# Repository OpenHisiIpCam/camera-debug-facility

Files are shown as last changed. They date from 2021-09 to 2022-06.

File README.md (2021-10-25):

# camera-debug-facility

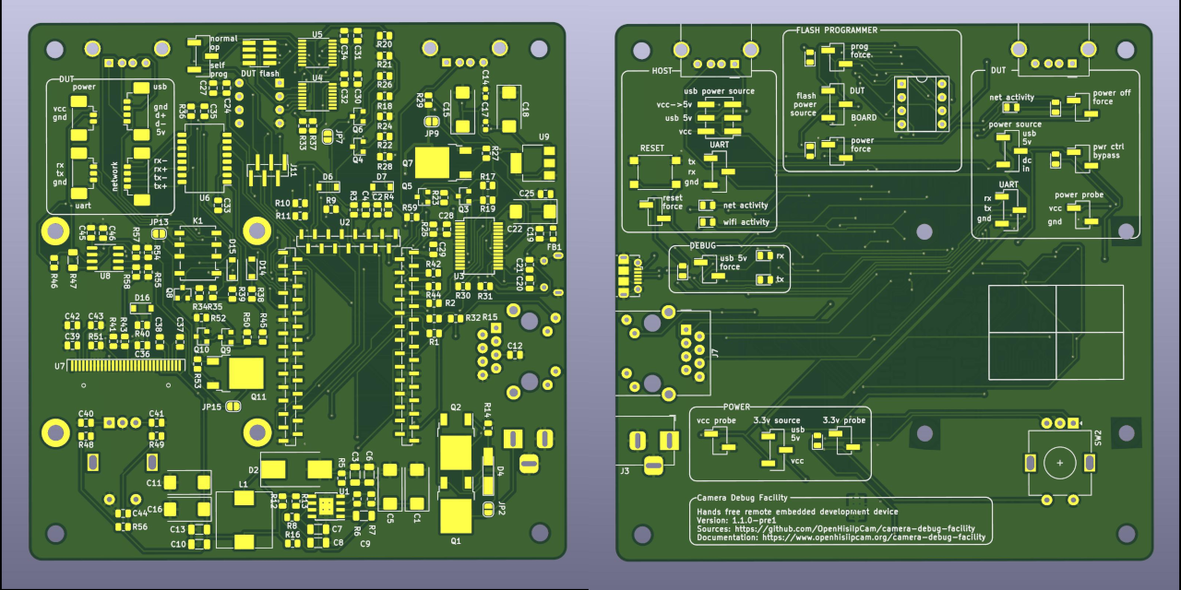
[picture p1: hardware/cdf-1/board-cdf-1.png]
Board


Hands free remote embedded development device.

End user documentation is hosted at https://www.openhisiipcam.org/camera-debug-facility.

## Overview schema

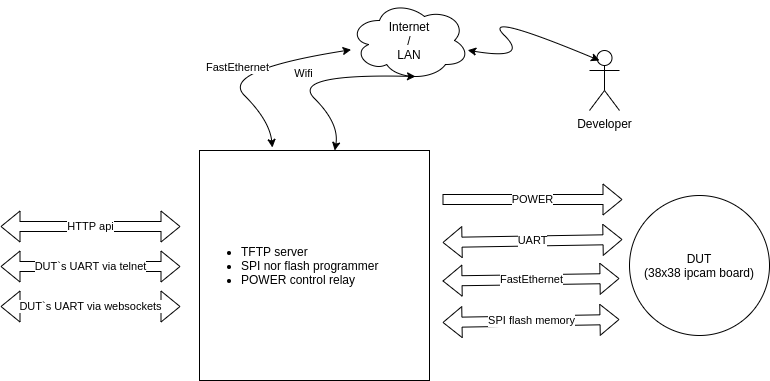
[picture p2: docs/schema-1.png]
Schema


## Schematics

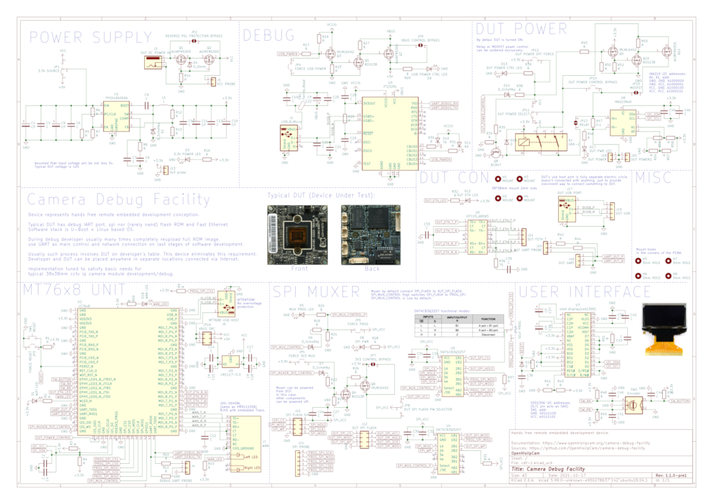
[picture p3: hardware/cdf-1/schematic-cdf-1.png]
Schematic

Can be found in `hardware/cdf-1`.

## Prototype

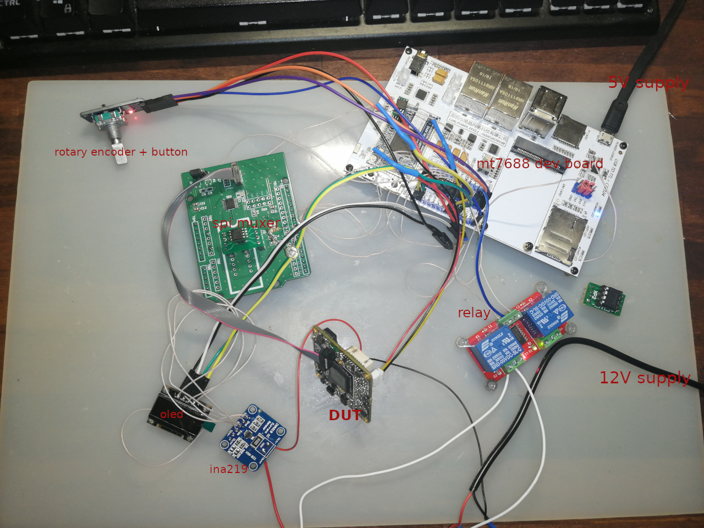
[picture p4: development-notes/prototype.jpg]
prototype


## Features

### Control interfaces
* FastEthernet
* WiFi (ap or client)
* http api
* uart via telnet
* uart via websockets
* spi flash programmer
* tftp server

### Dut control
* power via gpiod relay
* uart
* spi flash mem
* FastEthernet

## Implementation

### Proposed deploy schema

squashfs rootfs to ram
jffs2 user via overlay

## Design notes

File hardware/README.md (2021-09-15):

# Hardware 

* `adapters` - collection of adapters
* `arduino-muxed-programmer` - Muxed SPI serprog programmer, shield for Arduino UNO.
* `cdf-1` - TODO

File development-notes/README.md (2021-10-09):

# Development notes, tests nad prototyping

After several experiments:
* [spi programmin via muxer](./speed/)
* [oled and VA meter](./i2c/)
* [user control via gpio](./gpio-input/)

Altogether were assembled in prototype.

prototype

## Notes
* R3, R4 from arudino muxed programmer board were removed, as IO11 on dev board already has 10K pullup.

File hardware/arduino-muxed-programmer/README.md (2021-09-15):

# SPI muxed programmer shield for Arduino UNO

**Schematics sources unfortunately were lost for this project.**

## Reference

* https://github.com/urjaman/fast-usbserial
* https://github.com/urjaman/frser-duino

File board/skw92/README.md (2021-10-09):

# SKW92A/B

## Notes

**There is no SPI controller pins exposed by module**

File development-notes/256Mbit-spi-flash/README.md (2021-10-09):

# Issues with 32MB (265Mbit) spi flashes

After some tests of skw92x and hlk-76x8x, there were found, 
that these modules setup mt76x8 to SPI-NOR 3-Byte Addr, same
time they install 32MB W25Q256.V spi flash.

After first power up W25Q256.V most probably will be in default factory
setup and accept 3 byte addresses, then U-Boot will be loaded, it will
detect that spi flash can run 4 byte addr mode and dynamicly send command
to change mode, after sw reset, as flash will not be reseted it will
keep 4 byte addr mode, cpu will try to load something via 3 byte and 
nothing will happens.

That obviously prevent device to be software reseted.

Solutions are:
* Use 16MB flash (sometimes not possible, as such module will come with low RAM amount)
* Tune module to use 4-Byte Addr.

## SPI-NOR 4-Byte Addr

Two things should be done: 
1. W25Q256.V should be setuped to use 4 byte addr mode by default
2. mt76x8 should be setuped to use 4 byte addr mode by default

## W25Q256.V

As main sw for spi nor flash operations is flashrom, it was sad, that 
last master version (by 9 oct 2021) doesn't include any issue related
features.

But PR https://github.com/flashrom/flashrom/pull/34 was found.
PR includes several modifications, but commit with needed funcs
was separated 
https://github.com/flashrom/flashrom/pull/34/commits/197c4965d11065b39efe96e191acc2b7ac3450de.
It can be found here `huming2207-flashrom-windond-adp.patch`.

As it was done to some previous flashrom version it is not possible to 
apply it to last master, so a bit modifications were done
`flashrom-7b9c74f-windond-adp.patch`.

New cmd options:
```console
./flashrom -p ch341a_spi --adp-status -V
./flashrom -p ch341a_spi --adp-enable -V
./flashrom -p ch341a_spi --adp-disable -V
```

Two W25Q256.V were tested, one sucessfully setuped, one not.
Why? This is question for further research.

## mt76x8 boot modes

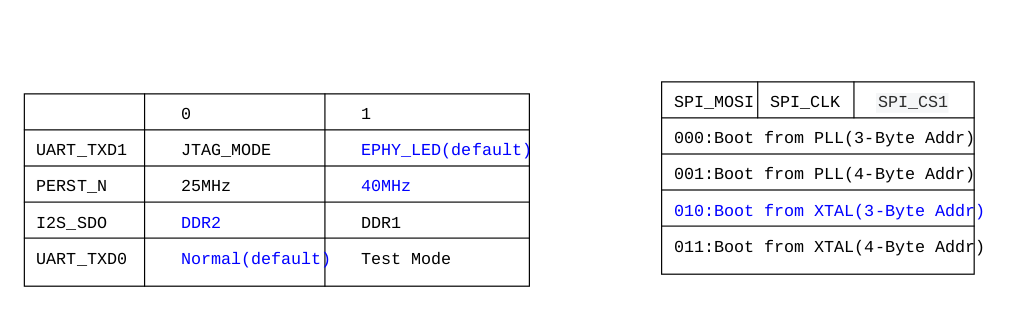
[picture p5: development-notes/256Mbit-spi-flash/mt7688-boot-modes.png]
mt7688-boot-modes


SPI_CS1 should be pulled up to power (3.3V).
But it already pulled down somewhere on the module, so to make 
high level low value resistance should be added.
It works.

## Further research
Maybe it is also possible to patch U-Boot and Linux kernel to 
use W25Q256.V in 3 byte addr mode and use not more than 16MB space.
Such way makes possible to use modules out of the box without any hw 
modifications.

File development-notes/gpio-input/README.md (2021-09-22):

# Rotary encoder with button

Encoder and button were connected to ordinary gpio.
No deep digging was done about parameters and other tuning.
First attempt (mostly out of the box) was fine.

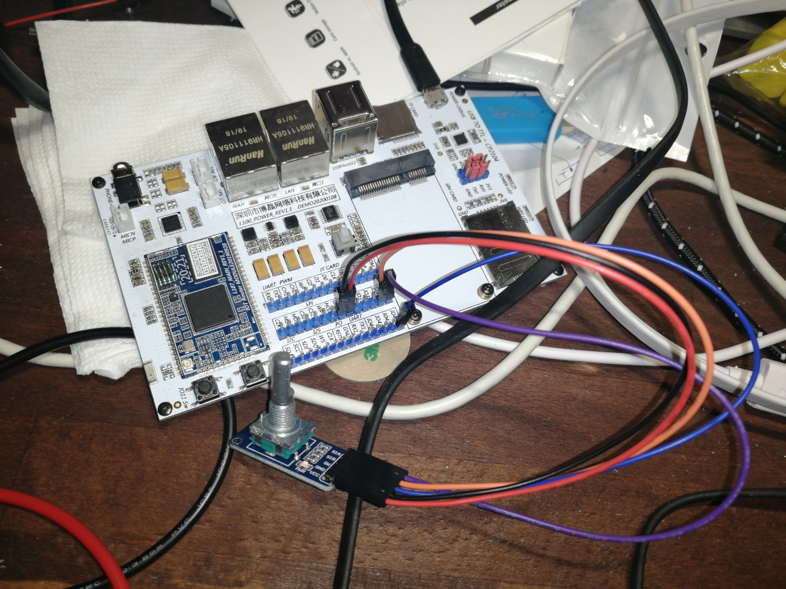
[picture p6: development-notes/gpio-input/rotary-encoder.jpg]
rotary-encoder


```
        rotary@0 {
                compatible = "rotary-encoder";
                gpios = <&gpio 39 0>, <&gpio 40 0>; /* GPIO19 is inverted */
                linux,axis = <1>; /* REL_X */
                rotary-encoder,encoding = "gray";
                rotary-encoder,relative-axis;
        };

        gpio-keys {
                compatible = "gpio-keys";
                autorepeat;

                left {
                        label = "GPIO Key UP";
                        linux,code = <69>; /* KEY_LEFT */
                        gpios = <&gpio 41 1>;
                };
        };
```

```console
# evtest 
No device specified, trying to scan all of /dev/input/event*
Available devices:
/dev/input/event0:	rotary@0
/dev/input/event1:	gpio-keys
Select the device event number [0-1]: 0
Input driver version is 1.0.1
Input device ID: bus 0x19 vendor 0x0 product 0x0 version 0x0
Input device name: "rotary@0"
Supported events:
  Event type 0 (EV_SYN)
  Event type 2 (EV_REL)
    Event code 1 (REL_Y)
Properties:
Testing ... (interrupt to exit)
Event: time 397.434583, type 2 (EV_REL), code 1 (REL_Y), value -1
Event: time 397.434583, -------------- SYN_REPORT ------------
Event: time 397.588939, type 2 (EV_REL), code 1 (REL_Y), value -1
Event: time 397.588939, -------------- SYN_REPORT ------------
Event: time 397.743230, type 2 (EV_REL), code 1 (REL_Y), value -1
Event: time 397.743230, -------------- SYN_REPORT ------------
Event: time 397.870931, type 2 (EV_REL), code 1 (REL_Y), value -1
Event: time 397.870931, -------------- SYN_REPORT ------------
Event: time 398.367746, type 2 (EV_REL), code 1 (REL_Y), value 1
Event: time 398.367746, -------------- SYN_REPORT ------------
```

```console
# evtest 
No device specified, trying to scan all of /dev/input/event*
Available devices:
/dev/input/event0:	rotary@0
/dev/input/event1:	gpio-keys
Select the device event number [0-1]: 1
Input driver version is 1.0.1
Input device ID: bus 0x19 vendor 0x1 product 0x1 version 0x100
Input device name: "gpio-keys"
Supported events:
  Event type 0 (EV_SYN)
  Event type 1 (EV_KEY)
    Event code 28 (KEY_ENTER)
Properties:
Testing ... (interrupt to exit)
Event: time 672.988025, type 1 (EV_KEY), code 28 (KEY_ENTER), value 1
Event: time 672.988025, -------------- SYN_REPORT ------------
Event: time 673.148034, type 1 (EV_KEY), code 28 (KEY_ENTER), value 0
Event: time 673.148034, -------------- SYN_REPORT ------------
Event: time 674.120034, type 1 (EV_KEY), code 28 (KEY_ENTER), value 1
Event: time 674.120034, -------------- SYN_REPORT ------------
Event: time 675.108034, type 1 (EV_KEY), code 28 (KEY_ENTER), value 0
Event: time 675.108034, -------------- SYN_REPORT ------------
```

*Events triggered on both leading and trailing edges of the signal.
During cursory examination there was not found wat to omit event with
value 0.*

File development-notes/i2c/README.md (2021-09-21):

# I2C devices

I2C bus was tested on 100kHz, 400kHz, 800kHz, 2MHz and 3.5Mhz.
At least this value was setuped to dts and corresponding value 
was detected in kernel boot log:
```
[    0.551150] i2c-mt7621 10000900.i2c: clock 800 kHz
```
*Suspected that real speed is less than 3.5MHz, clock signal check required.*

## OLED SSD1306 (128x64) via I2C

### User space

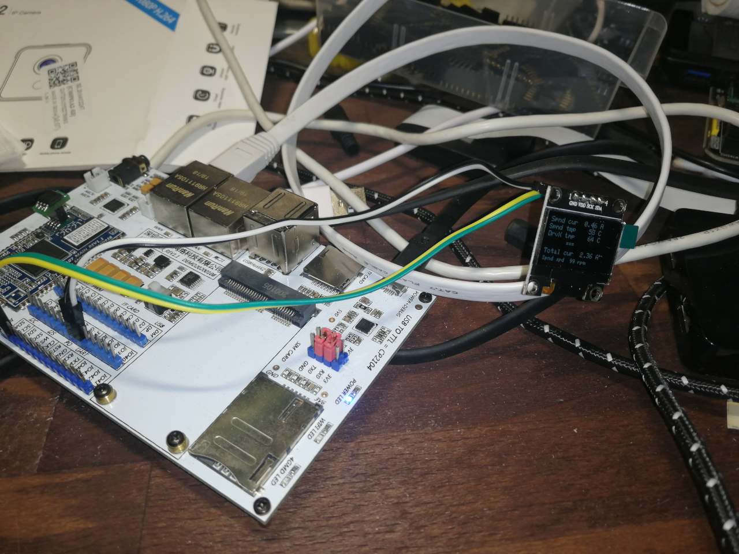
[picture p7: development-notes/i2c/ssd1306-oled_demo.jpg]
ssd1306-oled_demo


Device can be operated from suer space via `/dev/i2c-0`.
Sample application `package/ssd1306-demo`.

### Framebuffer via Linux native driver

Also device can be added to dts and accessed via `/dev/fb0`.

```
&i2c {
        status = "okay";

        oled@3c {
                compatible = "solomon,ssd1306fb-i2c";
                reg = <0x3c>;
                solomon,width = <128>;
                solomon,height = <64>;
                solomon,page-offset = <0>;
                solomon,com-invdir = <1>;
        };
};
```

## INA219

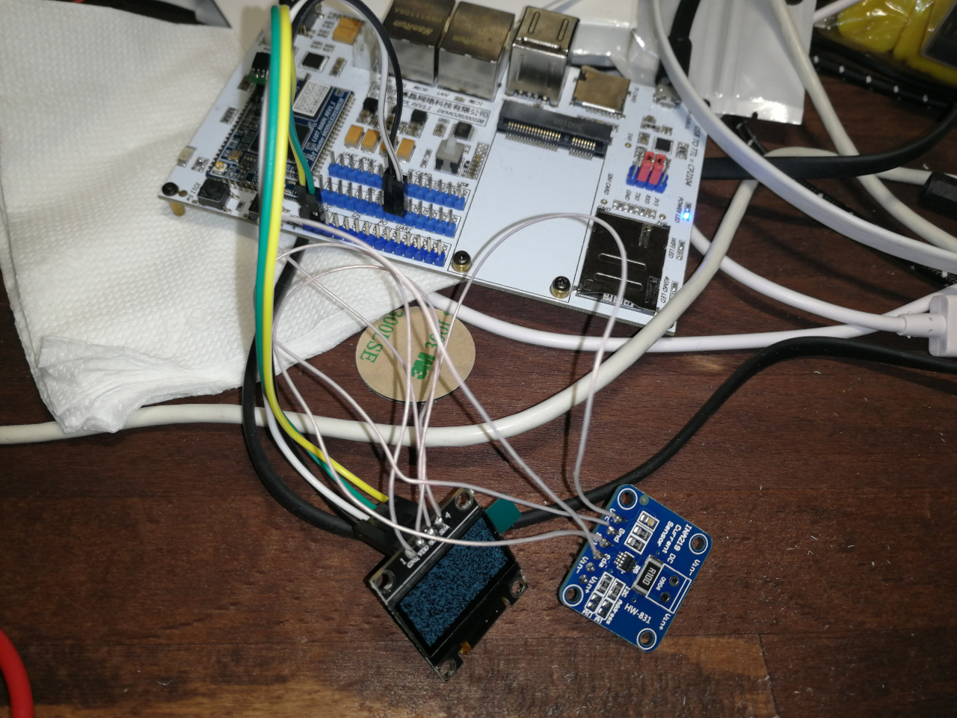
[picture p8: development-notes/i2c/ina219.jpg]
ina219


Same time another one I2C slave device can be connected to the same bus:
```
&i2c {
        status = "okay";
        clock-frequency = <400000>;

        oled@3c {
                compatible = "solomon,ssd1306fb-i2c";
                reg = <0x3c>;
                solomon,width = <128>;
                solomon,height = <64>;
                solomon,page-offset = <0>;
                solomon,com-invdir = <1>;
        };

        ina219@40 {
                compatible = "ti,ina219";
                reg = <0x40>;
                shunt-resistor = <100000>;
        };
};
```

```console
# i2cdetect -y 0
     0  1  2  3  4  5  6  7  8  9  a  b  c  d  e  f
00:                         -- -- -- -- -- -- -- -- 
10: -- -- -- -- -- -- -- -- -- -- 1a -- -- -- -- -- 
20: -- -- -- -- -- -- -- -- -- -- -- -- -- -- -- -- 
30: -- -- -- -- -- -- -- -- -- -- -- -- UU -- -- -- 
40: UU -- -- -- -- -- -- -- -- -- -- -- -- -- -- -- 
50: -- -- -- -- -- -- -- -- -- -- -- -- -- -- -- -- 
60: -- -- -- -- -- -- -- -- -- -- -- -- -- -- -- -- 
70: -- -- -- -- -- -- -- --      
```
* *UU means that device is not accesible from user space, but handled by kernel module.*
* *0x1a is audio codec on dev board, that also connected to same I2C bus.*

```console
# cat /sys/class/hwmon/hwmon0/name 
ina219
# sensors 
ina219-i2c-0-40
Adapter: 10000900.i2c
in0:           0.00 V  
in1:         852.00 mV 
power1:        0.00 W  
curr1:       -1000.00 uA 
```

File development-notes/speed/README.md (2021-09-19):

# SPI read speed measurements

In short: 35MHz read spead was achived via muxer based on SN74CB3Q3257PW ICs.
32MB read speed was a bit more than 10 seconds.

## Notes

[Arduino muxed programmer](../../hardware/arduino-muxed-programmer) PCBA were connected to MT7688 dev board.
74HC514 was removed (connections replaced with wires), as we actually
don't need here 5v to 3.3v convertion (as it was it's function) and
it was affecting MT7688's ROM boot (it also seat on same spi controller,
but with different CS).

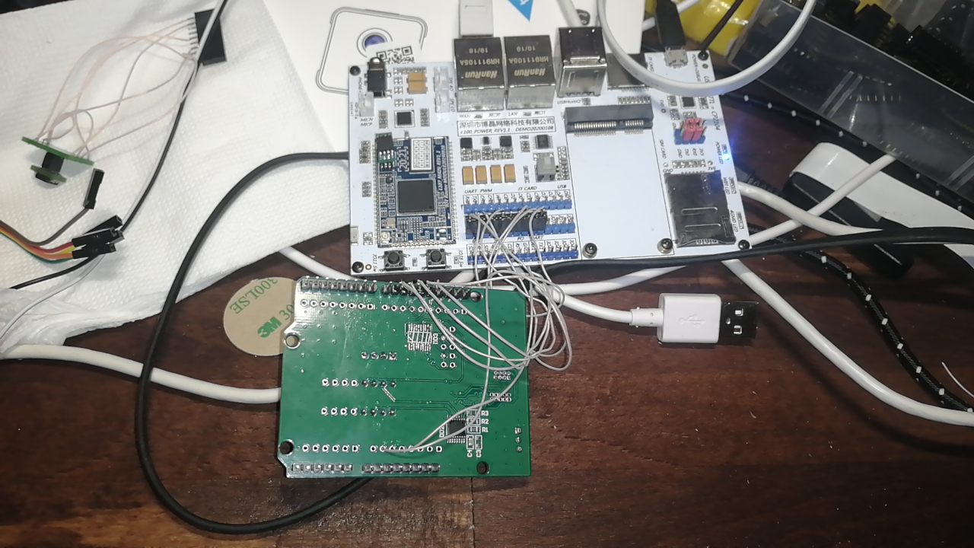
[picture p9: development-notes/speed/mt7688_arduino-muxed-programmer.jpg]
mt7688_arduino-muxed-programmer


SPI speed was limited via Linux's dts by 40MHz.
```
        spidev@1 {
                #address-cells = <1>;
                #size-cells = <1>;
                compatible = "linux,spidev";
                reg = <1>;
                spi-max-frequency = <40000000>;
        };
```

## MT7688 W25Q128.V 16MB DIP via muxer on wires

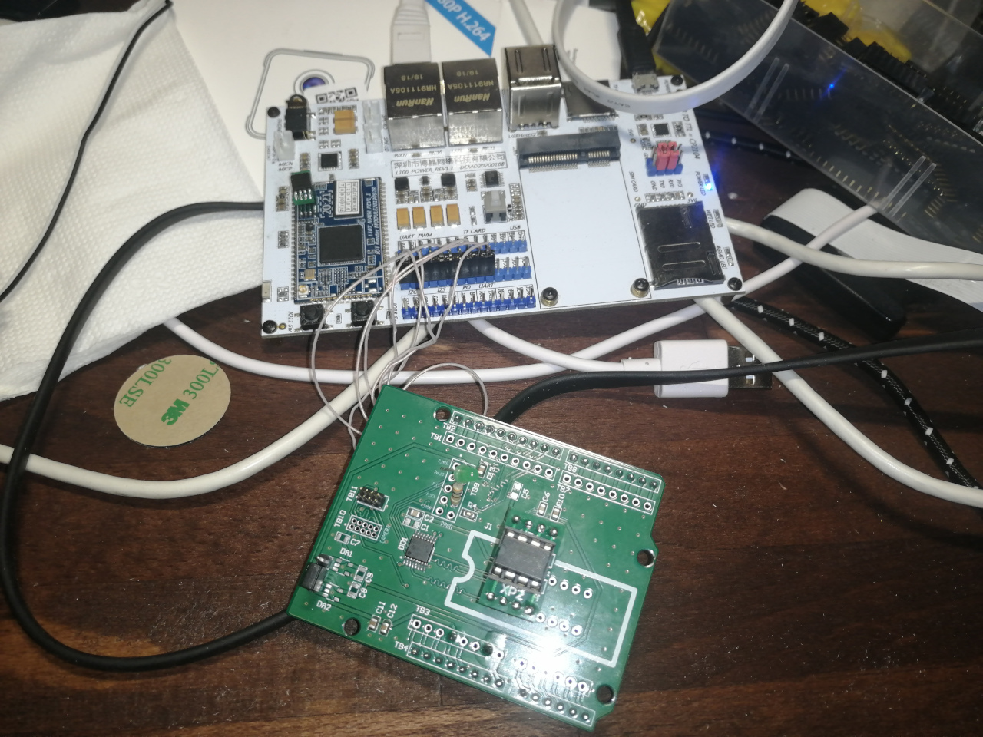
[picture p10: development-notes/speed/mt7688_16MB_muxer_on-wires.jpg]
mt7688_16MB_muxer_on-wires


```console
# time flashrom --programmer linux_spi:dev=/dev/spidev0.1,spispeed=1000 -r /tmp/1
flashrom  on Linux 5.4.143 (mips)
flashrom is free software, get the source code at https://flashrom.org

Using clock_gettime for delay loops (clk_id: 1, resolution: 1ns).
Found Winbond flash chip "W25Q128.V" (16384 kB, SPI) on linux_spi.
Reading flash... done.
real	2m 16.50s
user	0m 0.01s
sys	2m 16.44s
# time flashrom --programmer linux_spi:dev=/dev/spidev0.1,spispeed=2000 -r /tmp/1
flashrom  on Linux 5.4.143 (mips)
flashrom is free software, get the source code at https://flashrom.org

Using clock_gettime for delay loops (clk_id: 1, resolution: 1ns).
Found Winbond flash chip "W25Q128.V" (16384 kB, SPI) on linux_spi.
Reading flash... done.
real	1m 9.03s
user	0m 0.05s
sys	1m 8.93s
# time flashrom --programmer linux_spi:dev=/dev/spidev0.1,spispeed=4000 -r /tmp/1
flashrom  on Linux 5.4.143 (mips)
flashrom is free software, get the source code at https://flashrom.org

Using clock_gettime for delay loops (clk_id: 1, resolution: 1ns).
Found Winbond flash chip "W25Q128.V" (16384 kB, SPI) on linux_spi.
Reading flash... done.
real	0m 35.58s
user	0m 0.02s
sys	0m 35.51s
# time flashrom --programmer linux_spi:dev=/dev/spidev0.1,spispeed=8000 -r /tmp/1
flashrom  on Linux 5.4.143 (mips)
flashrom is free software, get the source code at https://flashrom.org

Using clock_gettime for delay loops (clk_id: 1, resolution: 1ns).
Found Winbond flash chip "W25Q128.V" (16384 kB, SPI) on linux_spi.
Reading flash... done.
real	0m 19.50s
user	0m 0.01s
sys	0m 19.44s
# time flashrom --programmer linux_spi:dev=/dev/spidev0.1,spispeed=10000 -r /tmp/1
flashrom  on Linux 5.4.143 (mips)
flashrom is free software, get the source code at https://flashrom.org

Using clock_gettime for delay loops (clk_id: 1, resolution: 1ns).
Found Winbond flash chip "W25Q128.V" (16384 kB, SPI) on linux_spi.
Reading flash... done.
real	0m 15.92s
user	0m 0.00s
sys	0m 15.87s
# time flashrom --programmer linux_spi:dev=/dev/spidev0.1,spispeed=15000 -r /tmp/1
flashrom  on Linux 5.4.143 (mips)
flashrom is free software, get the source code at https://flashrom.org

Using clock_gettime for delay loops (clk_id: 1, resolution: 1ns).
Found Winbond flash chip "W25Q128.V" (16384 kB, SPI) on linux_spi.
Reading flash... done.
real	0m 11.10s
user	0m 0.01s
sys	0m 11.04s
# time flashrom --programmer linux_spi:dev=/dev/spidev0.1,spispeed=18000 -r /tmp/1
flashrom  on Linux 5.4.143 (mips)
flashrom is free software, get the source code at https://flashrom.org

Using clock_gettime for delay loops (clk_id: 1, resolution: 1ns).
Found Winbond flash chip "W25Q128.V" (16384 kB, SPI) on linux_spi.
Reading flash... done.
real	0m 9.30s
user	0m 0.03s
sys	0m 9.22s
# time flashrom --programmer linux_spi:dev=/dev/spidev0.1,spispeed=20000 -r /tmp/1
flashrom  on Linux 5.4.143 (mips)
flashrom is free software, get the source code at https://flashrom.org

Using clock_gettime for delay loops (clk_id: 1, resolution: 1ns).
Found Winbond flash chip "unknown Winbond (ex Nexcom) SPI chip" (0 kB, SPI) on linux_spi.
===
This flash part has status NOT WORKING for operations: PROBE READ ERASE WRITE
The test status of this chip may have been updated in the latest development
version of flashrom. If you are running the latest development version,
please email a report to flashrom@flashrom.org if any of the above operations
work correctly for you with this flash chip. Please include the flashrom log
file for all operations you tested (see the man page for details), and mention
which mainboard or programmer you tested in the subject line.
Thanks for your help!
Read is not working on this chip. Aborting.
Command exited with non-zero status 1
real	0m 0.11s
user	0m 0.01s
sys	0m 0.09s
# time flashrom --programmer linux_spi:dev=/dev/spidev0.1,spispeed=18000 -r /tmp/1
flashrom  on Linux 5.4.143 (mips)
flashrom is free software, get the source code at https://flashrom.org

Using clock_gettime for delay loops (clk_id: 1, resolution: 1ns).
Found Winbond flash chip "W25Q128.V" (16384 kB, SPI) on linux_spi.
Reading flash... done.
real	0m 9.30s
user	0m 0.02s
sys	0m 9.23s
```

## MT7688 MX25L25635F/MX25L25645G 32MB via muxer on wires

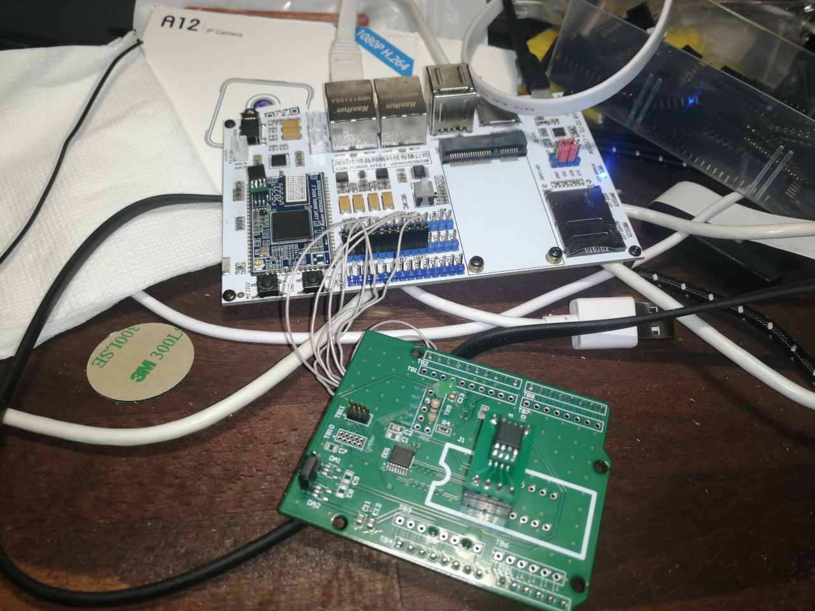
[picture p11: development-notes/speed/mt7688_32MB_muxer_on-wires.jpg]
mt7688_32MB_muxer_on-wires


```console
# time flashrom --programmer linux_spi:dev=/dev/spidev0.1,spispeed=1000 -r /tmp/1
flashrom  on Linux 5.4.143 (mips)
flashrom is free software, get the source code at https://flashrom.org

Using clock_gettime for delay loops (clk_id: 1, resolution: 1ns).
Found Macronix flash chip "MX25L25635F/MX25L25645G" (32768 kB, SPI) on linux_spi.
Reading flash... done.
real	4m 32.96s
user	0m 0.01s
sys	4m 32.85s
# time flashrom --programmer linux_spi:dev=/dev/spidev0.1,spispeed=2000 -r /tmp/1
flashrom  on Linux 5.4.143 (mips)
flashrom is free software, get the source code at https://flashrom.org

Using clock_gettime for delay loops (clk_id: 1, resolution: 1ns).
Found Macronix flash chip "MX25L25635F/MX25L25645G" (32768 kB, SPI) on linux_spi.
Reading flash... done.
real	2m 18.07s
user	0m 0.01s
sys	2m 17.96s
# time flashrom --programmer linux_spi:dev=/dev/spidev0.1,spispeed=4000 -r /tmp/1
flashrom  on Linux 5.4.143 (mips)
flashrom is free software, get the source code at https://flashrom.org

Using clock_gettime for delay loops (clk_id: 1, resolution: 1ns).
Found Macronix flash chip "MX25L25635F/MX25L25645G" (32768 kB, SPI) on linux_spi.
Reading flash... done.
real	1m 11.06s
user	0m 0.04s
sys	1m 10.91s
# time flashrom --programmer linux_spi:dev=/dev/spidev0.1,spispeed=8000 -r /tmp/1
flashrom  on Linux 5.4.143 (mips)
flashrom is free software, get the source code at https://flashrom.org

Using clock_gettime for delay loops (clk_id: 1, resolution: 1ns).
Found Macronix flash chip "MX25L25635F/MX25L25645G" (32768 kB, SPI) on linux_spi.
Reading flash... done.
real	0m 38.89s
user	0m 0.05s
sys	0m 38.73s
# time flashrom --programmer linux_spi:dev=/dev/spidev0.1,spispeed=10000 -r /tmp/1
flashrom  on Linux 5.4.143 (mips)
flashrom is free software, get the source code at https://flashrom.org

Using clock_gettime for delay loops (clk_id: 1, resolution: 1ns).
Found Macronix flash chip "MX25L25635F/MX25L25645G" (32768 kB, SPI) on linux_spi.
Reading flash... done.
real	0m 31.68s
user	0m 0.03s
sys	0m 31.55s
# time flashrom --programmer linux_spi:dev=/dev/spidev0.1,spispeed=15000 -r /tmp/1
flashrom  on Linux 5.4.143 (mips)
flashrom is free software, get the source code at https://flashrom.org

Using clock_gettime for delay loops (clk_id: 1, resolution: 1ns).
Found Macronix flash chip "MX25L25635F/MX25L25645G" (32768 kB, SPI) on linux_spi.
Reading flash... done.
real	0m 22.10s
user	0m 0.01s
sys	0m 22.00s
# time flashrom --programmer linux_spi:dev=/dev/spidev0.1,spispeed=18000 -r /tmp/1
flashrom  on Linux 5.4.143 (mips)
flashrom is free software, get the source code at https://flashrom.org

Using clock_gettime for delay loops (clk_id: 1, resolution: 1ns).
Found Macronix flash chip "MX25L25635F/MX25L25645G" (32768 kB, SPI) on linux_spi.
Reading flash... done.
real	0m 18.49s
user	0m 0.06s
sys	0m 18.34s
# time flashrom --programmer linux_spi:dev=/dev/spidev0.1,spispeed=20000 -r /tmp/1
flashrom  on Linux 5.4.143 (mips)
flashrom is free software, get the source code at https://flashrom.org

Using clock_gettime for delay loops (clk_id: 1, resolution: 1ns).
Found Macronix flash chip "MX25L25635F/MX25L25645G" (32768 kB, SPI) on linux_spi.
Reading flash... done.
real	0m 17.27s
user	0m 0.03s
sys	0m 17.15s
# time flashrom --programmer linux_spi:dev=/dev/spidev0.1,spispeed=25000 -r /tmp/1
flashrom  on Linux 5.4.143 (mips)
flashrom is free software, get the source code at https://flashrom.org

Using clock_gettime for delay loops (clk_id: 1, resolution: 1ns).
Found Macronix flash chip "MX25L25635F/MX25L25645G" (32768 kB, SPI) on linux_spi.
Reading flash... done.
real	0m 14.87s
user	0m 0.03s
sys	0m 14.75s
# time flashrom --programmer linux_spi:dev=/dev/spidev0.1,spispeed=30000 -r /tmp/1
flashrom  on Linux 5.4.143 (mips)
flashrom is free software, get the source code at https://flashrom.org

Using clock_gettime for delay loops (clk_id: 1, resolution: 1ns).
Found Macronix flash chip "MX25L25635F/MX25L25645G" (32768 kB, SPI) on linux_spi.
Reading flash... done.
real	0m 13.66s
user	0m 0.04s
sys	0m 13.53s
# time flashrom --programmer linux_spi:dev=/dev/spidev0.1,spispeed=35000 -r /tmp/1
flashrom  on Linux 5.4.143 (mips)
flashrom is free software, get the source code at https://flashrom.org

Using clock_gettime for delay loops (clk_id: 1, resolution: 1ns).
Found Macronix flash chip "unknown Macronix SPI chip" (0 kB, SPI) on linux_spi.
===
This flash part has status NOT WORKING for operations: PROBE READ ERASE WRITE
The test status of this chip may have been updated in the latest development
version of flashrom. If you are running the latest development version,
please email a report to flashrom@flashrom.org if any of the above operations
work correctly for you with this flash chip. Please include the flashrom log
file for all operations you tested (see the man page for details), and mention
which mainboard or programmer you tested in the subject line.
Thanks for your help!
Read is not working on this chip. Aborting.
Command exited with non-zero status 1
real	0m 0.11s
user	0m 0.01s
sys	0m 0.09s
# time flashrom --programmer linux_spi:dev=/dev/spidev0.1,spispeed=30000 -r /tmp/1
flashrom  on Linux 5.4.143 (mips)
flashrom is free software, get the source code at https://flashrom.org

Using clock_gettime for delay loops (clk_id: 1, resolution: 1ns).
Found Macronix flash chip "MX25L25635F/MX25L25645G" (32768 kB, SPI) on linux_spi.
Reading flash... done.
real	0m 13.63s
user	0m 0.04s
sys	0m 13.51s
```

## MT7688 MX25L25635F/MX25L25645G 32MB on wires

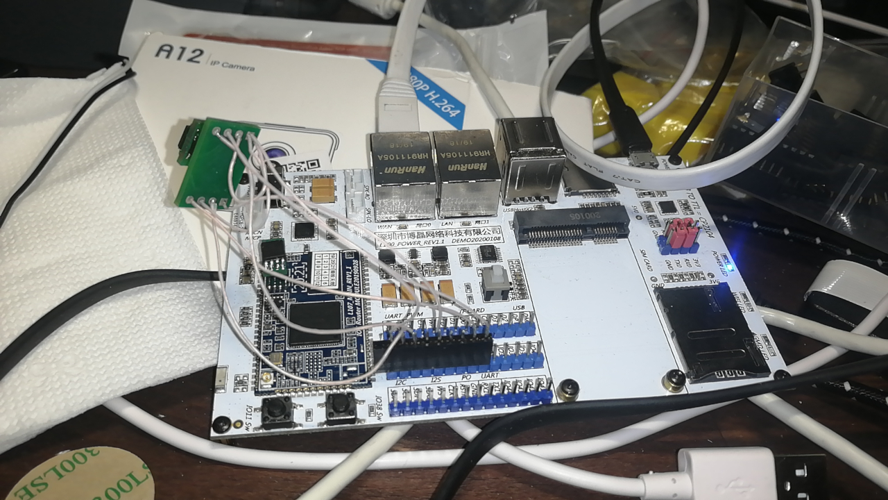
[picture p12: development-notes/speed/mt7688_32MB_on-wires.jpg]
mt7688_32MB_on-wires


```console
# time flashrom --programmer linux_spi:dev=/dev/spidev0.1,spispeed=1000 -r /tmp/1
flashrom  on Linux 5.4.143 (mips)
flashrom is free software, get the source code at https://flashrom.org

Using clock_gettime for delay loops (clk_id: 1, resolution: 1ns).
Found Macronix flash chip "MX25L25635F/MX25L25645G" (32768 kB, SPI) on linux_spi.
Reading flash... done.
real	4m 32.94s
user	0m 0.02s
sys	4m 32.82s
# time flashrom --programmer linux_spi:dev=/dev/spidev0.1,spispeed=2000 -r /tmp/1
flashrom  on Linux 5.4.143 (mips)
flashrom is free software, get the source code at https://flashrom.org

Using clock_gettime for delay loops (clk_id: 1, resolution: 1ns).
Found Macronix flash chip "MX25L25635F/MX25L25645G" (32768 kB, SPI) on linux_spi.
Reading flash... done.
real	2m 18.08s
user	0m 0.02s
sys	2m 17.96s
# time flashrom --programmer linux_spi:dev=/dev/spidev0.1,spispeed=4000 -r /tmp/1
flashrom  on Linux 5.4.143 (mips)
flashrom is free software, get the source code at https://flashrom.org

Using clock_gettime for delay loops (clk_id: 1, resolution: 1ns).
Found Macronix flash chip "MX25L25635F/MX25L25645G" (32768 kB, SPI) on linux_spi.
Reading flash... done.
real	1m 11.09s
user	0m 0.03s
sys	1m 10.96s
# time flashrom --programmer linux_spi:dev=/dev/spidev0.1,spispeed=8000 -r /tmp/1
flashrom  on Linux 5.4.143 (mips)
flashrom is free software, get the source code at https://flashrom.org

Using clock_gettime for delay loops (clk_id: 1, resolution: 1ns).
Found Macronix flash chip "MX25L25635F/MX25L25645G" (32768 kB, SPI) on linux_spi.
Reading flash... done.
real	0m 38.89s
user	0m 0.05s
sys	0m 38.75s
# time flashrom --programmer linux_spi:dev=/dev/spidev0.1,spispeed=10000 -r /tmp/1
flashrom  on Linux 5.4.143 (mips)
flashrom is free software, get the source code at https://flashrom.org

Using clock_gettime for delay loops (clk_id: 1, resolution: 1ns).
Found Macronix flash chip "MX25L25635F/MX25L25645G" (32768 kB, SPI) on linux_spi.
Reading flash... done.
real	0m 31.68s
user	0m 0.02s
sys	0m 31.56s
# time flashrom --programmer linux_spi:dev=/dev/spidev0.1,spispeed=15000 -r /tmp/1
flashrom  on Linux 5.4.143 (mips)
flashrom is free software, get the source code at https://flashrom.org

Using clock_gettime for delay loops (clk_id: 1, resolution: 1ns).
Found Macronix flash chip "MX25L25635F/MX25L25645G" (32768 kB, SPI) on linux_spi.
Reading flash... done.
real	0m 22.11s
user	0m 0.06s
sys	0m 21.96s
# time flashrom --programmer linux_spi:dev=/dev/spidev0.1,spispeed=18000 -r /tmp/1
flashrom  on Linux 5.4.143 (mips)
flashrom is free software, get the source code at https://flashrom.org

Using clock_gettime for delay loops (clk_id: 1, resolution: 1ns).
Found Macronix flash chip "MX25L25635F/MX25L25645G" (32768 kB, SPI) on linux_spi.
Reading flash... done.
real	0m 18.51s
user	0m 0.02s
sys	0m 18.40s
# time flashrom --programmer linux_spi:dev=/dev/spidev0.1,spispeed=20000 -r /tmp/1
flashrom  on Linux 5.4.143 (mips)
flashrom is free software, get the source code at https://flashrom.org

Using clock_gettime for delay loops (clk_id: 1, resolution: 1ns).
Found Macronix flash chip "MX25L25635F/MX25L25645G" (32768 kB, SPI) on linux_spi.
Reading flash... done.
real	0m 17.27s
user	0m 0.02s
sys	0m 17.17s
# time flashrom --programmer linux_spi:dev=/dev/spidev0.1,spispeed=25000 -r /tmp/1
flashrom  on Linux 5.4.143 (mips)
flashrom is free software, get the source code at https://flashrom.org

Using clock_gettime for delay loops (clk_id: 1, resolution: 1ns).
Found Macronix flash chip "MX25L25635F/MX25L25645G" (32768 kB, SPI) on linux_spi.
Reading flash... done.
real	0m 14.87s
user	0m 0.06s
sys	0m 14.72s
# time flashrom --programmer linux_spi:dev=/dev/spidev0.1,spispeed=30000 -r /tmp/1
flashrom  on Linux 5.4.143 (mips)
flashrom is free software, get the source code at https://flashrom.org

Using clock_gettime for delay loops (clk_id: 1, resolution: 1ns).
Found Macronix flash chip "MX25L25635F/MX25L25645G" (32768 kB, SPI) on linux_spi.
Reading flash... done.
real	0m 13.63s
user	0m 0.02s
sys	0m 13.52s
# time flashrom --programmer linux_spi:dev=/dev/spidev0.1,spispeed=35000 -r /tmp/1
flashrom  on Linux 5.4.143 (mips)
flashrom is free software, get the source code at https://flashrom.org

Using clock_gettime for delay loops (clk_id: 1, resolution: 1ns).
Found Macronix flash chip "MX25L25635F/MX25L25645G" (32768 kB, SPI) on linux_spi.
Reading flash... done.
real	0m 11.26s
user	0m 0.03s
sys	0m 11.15s
# time flashrom --programmer linux_spi:dev=/dev/spidev0.1,spispeed=40000 -r /tmp/1
flashrom  on Linux 5.4.143 (mips)
flashrom is free software, get the source code at https://flashrom.org

Using clock_gettime for delay loops (clk_id: 1, resolution: 1ns).
Found Macronix flash chip "MX25L25635F/MX25L25645G" (32768 kB, SPI) on linux_spi.
Reading flash... done.
real	0m 10.03s
user	0m 0.05s
sys	0m 9.90s
```

## CH341 MX25L25635F/MX25L25645G 32MB on socket

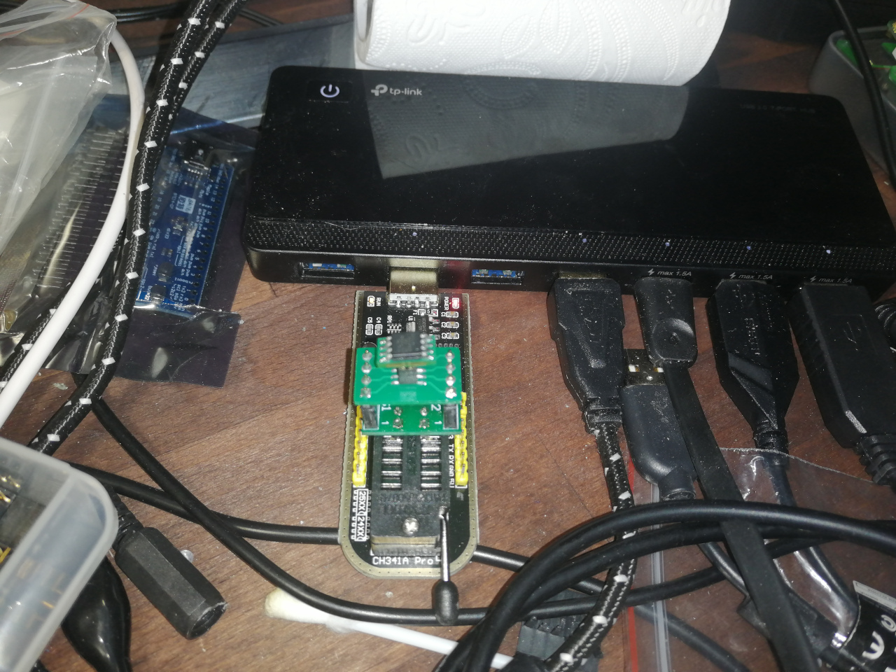
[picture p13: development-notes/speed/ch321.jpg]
ch321


From flashrom man page:
```
ch341a_spi programmer
The WCH CH341A programmer does not support any parameters currently. SPI frequency is fixed at 2 MHz, and CS0 is used as per the device.
```

```console
$ sudo time vendors/flashrom/flashrom --programmer ch341a_spi -r /tmp/1
flashrom  on Linux 4.18.0-25-generic (x86_64)
flashrom is free software, get the source code at https://flashrom.org

Using clock_gettime for delay loops (clk_id: 1, resolution: 1ns).
Found Macronix flash chip "MX25L25635F/MX25L25645G" (32768 kB, SPI) on ch341a_spi.
Reading flash... done.
9.62user 15.29system 4:31.08elapsed 9%CPU (0avgtext+0avgdata 36092maxresident)k
0inputs+65536outputs (0major+8447minor)pagefaults 0swaps
```

## Attempt to get more

Linux dts was changed to allow up to 100MHz spi speed.
32MB flash was tested connected directly (without muxer). 
Seems ~45MHz is max speed, that can be achived 
(at least with connection via wires).

```console
# time flashrom --programmer linux_spi:dev=/dev/spidev0.1,spispeed=45000 -r /tmp/1
flashrom  on Linux 5.4.143 (mips)
flashrom is free software, get the source code at https://flashrom.org

Using clock_gettime for delay loops (clk_id: 1, resolution: 1ns).
Found Macronix flash chip "MX25L25635F/MX25L25645G" (32768 kB, SPI) on linux_spi.
Reading flash... done.
real	0m 10.05s
user	0m 0.03s
sys	0m 9.94s
# time flashrom --programmer linux_spi:dev=/dev/spidev0.1,spispeed=45000 -v /tmp/1
flashrom  on Linux 5.4.143 (mips)
flashrom is free software, get the source code at https://flashrom.org

Using clock_gettime for delay loops (clk_id: 1, resolution: 1ns).
Found Macronix flash chip "MX25L25635F/MX25L25645G" (32768 kB, SPI) on linux_spi.
Verifying flash... VERIFIED.
real	0m 10.90s
user	0m 0.89s
sys	0m 9.93s
# time flashrom --programmer linux_spi:dev=/dev/spidev0.1,spispeed=47000 -v /tmp/1
flashrom  on Linux 5.4.143 (mips)
flashrom is free software, get the source code at https://flashrom.org

Using clock_gettime for delay loops (clk_id: 1, resolution: 1ns).
Found Macronix flash chip "MX25L25635F/MX25L25645G" (32768 kB, SPI) on linux_spi.
Verifying flash... VERIFIED.
real	0m 10.88s
user	0m 0.89s
sys	0m 9.91s
# time flashrom --programmer linux_spi:dev=/dev/spidev0.1,spispeed=48000 -v /tmp/1
flashrom  on Linux 5.4.143 (mips)
flashrom is free software, get the source code at https://flashrom.org

Using clock_gettime for delay loops (clk_id: 1, resolution: 1ns).
Found Macronix flash chip "MX25L25635F/MX25L25645G" (32768 kB, SPI) on linux_spi.
Verifying flash... VERIFIED.
real	0m 10.87s
user	0m 0.87s
sys	0m 9.92s
# time flashrom --programmer linux_spi:dev=/dev/spidev0.1,spispeed=49000 -v /tmp/1
flashrom  on Linux 5.4.143 (mips)
flashrom is free software, get the source code at https://flashrom.org

Using clock_gettime for delay loops (clk_id: 1, resolution: 1ns).
Found Macronix flash chip "MX25L25635F/MX25L25645G" (32768 kB, SPI) on linux_spi.
Verifying flash... FAILED at 0x0000030b! Expected=0x24, Found=0x34, failed byte count from 0x00000000-0x01ffffff: 0x325e
Command exited with non-zero status 3
real	0m 9.67s
user	0m 0.90s
sys	0m 8.69s
```

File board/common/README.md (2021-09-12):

# OpenWRT BSP extract

linux-5.4.143

---

wget https://github.com/openwrt/openwrt/archive/refs/tags/v21.02.0.tar.gz
unpack
./scripts/feeds update -a
./scripts/feeds install -a
make

make target/linux/prepare  QUILT=1 V=s
```
nikita@nikita-ThinkPad-T450:~/ohic/REPO/camera-debug-facility/tmp/openwrt-21.02.0$ make target/linux/prepare  QUILT=1 V=s
make[1]: Entering directory '/home/nikita/ohic/REPO/camera-debug-facility/tmp/openwrt-21.02.0'
make[2]: Entering directory '/home/nikita/ohic/REPO/camera-debug-facility/tmp/openwrt-21.02.0/target/linux'
make[3]: Entering directory '/home/nikita/ohic/REPO/camera-debug-facility/tmp/openwrt-21.02.0/target/linux/ramips'
rm -rf /home/nikita/ohic/REPO/camera-debug-facility/tmp/openwrt-21.02.0/build_dir/target-mipsel_24kc_musl/linux-ramips_mt76x8
mkdir -p /home/nikita/ohic/REPO/camera-debug-facility/tmp/openwrt-21.02.0/build_dir/target-mipsel_24kc_musl/linux-ramips_mt76x8
xzcat /home/nikita/ohic/REPO/camera-debug-facility/tmp/openwrt-21.02.0/dl/linux-5.4.143.tar.xz | tar -C /home/nikita/ohic/REPO/camera-debug-facility/tmp/openwrt-21.02.0/build_dir/target-mipsel_24kc_musl/linux-ramips_mt76x8 -xf -
rm -rf /home/nikita/ohic/REPO/camera-debug-facility/tmp/openwrt-21.02.0/build_dir/target-mipsel_24kc_musl/linux-ramips_mt76x8/linux-5.4.143/patches; mkdir -p /home/nikita/ohic/REPO/camera-debug-facility/tmp/openwrt-21.02.0/build_dir/target-mipsel_24kc_musl/linux-ramips_mt76x8/linux-5.4.143/patches
cp -fpR "/home/nikita/ohic/REPO/camera-debug-facility/tmp/openwrt-21.02.0/target/linux/generic/files"/. "/home/nikita/ohic/REPO/camera-debug-facility/tmp/openwrt-21.02.0/target/linux/ramips/files"/. /home/nikita/ohic/REPO/camera-debug-facility/tmp/openwrt-21.02.0/build_dir/target-mipsel_24kc_musl/linux-ramips_mt76x8/linux-5.4.143/
find /home/nikita/ohic/REPO/camera-debug-facility/tmp/openwrt-21.02.0/build_dir/target-mipsel_24kc_musl/linux-ramips_mt76x8/linux-5.4.143/ -name \*.rej -or -name \*.orig | xargs -r rm -f
if [ -d /home/nikita/ohic/REPO/camera-debug-facility/tmp/openwrt-21.02.0/target/linux/generic/patches ]; then echo "generic patches directory is present. please move your patches to the pending directory" ; exit 1; fi
touch /home/nikita/ohic/REPO/camera-debug-facility/tmp/openwrt-21.02.0/build_dir/target-mipsel_24kc_musl/linux-ramips_mt76x8/linux-5.4.143/.quilt_used
touch /home/nikita/ohic/REPO/camera-debug-facility/tmp/openwrt-21.02.0/build_dir/target-mipsel_24kc_musl/linux-ramips_mt76x8/linux-5.4.143/.prepared
make[3]: Leaving directory '/home/nikita/ohic/REPO/camera-debug-facility/tmp/openwrt-21.02.0/target/linux/ramips'
make[2]: Leaving directory '/home/nikita/ohic/REPO/camera-debug-facility/tmp/openwrt-21.02.0/target/linux'
time: target/linux/prepare#11.18#3.58#11.74
make[1]: Leaving directory '/home/nikita/ohic/REPO/camera-debug-facility/tmp/openwrt-21.02.0'
```

TODO HOWTO dts
TODO HOWTO files

build_dir/target-mipsel_24kc_musl/linux-ramips_mt76x8/linux-5.4.143/patches

build_dir/target-mipsel_24kc_musl/linux-ramips_mt76x8/backports-5.10.42-1/patches
```
nikita@nikita-ThinkPad-T450:~/ohic/REPO/camera-debug-facility/tmp/openwrt-21.02.0$ make package/kernel/mac80211/prepare  QUILT=1 V=s
make[1]: Entering directory '/home/nikita/ohic/REPO/camera-debug-facility/tmp/openwrt-21.02.0'
make[2]: Entering directory '/home/nikita/ohic/REPO/camera-debug-facility/tmp/openwrt-21.02.0/package/kernel/mac80211'
mkdir -p /home/nikita/ohic/REPO/camera-debug-facility/tmp/openwrt-21.02.0/dl
SHELL= flock /home/nikita/ohic/REPO/camera-debug-facility/tmp/openwrt-21.02.0/tmp/.backports-5.10.42-1.tar.xz.flock -c '  	/home/nikita/ohic/REPO/camera-debug-facility/tmp/openwrt-21.02.0/scripts/download.pl "/home/nikita/ohic/REPO/camera-debug-facility/tmp/openwrt-21.02.0/dl" "backports-5.10.42-1.tar.xz" "6876520105240844fdb32d1dcdf2bfdea291a37a96f16c892fda3776ba714fcb" "" "@KERNEL/linux/kernel/projects/backports/stable/v5.10.42/"    '
touch /home/nikita/ohic/REPO/camera-debug-facility/tmp/openwrt-21.02.0/build_dir/target-mipsel_24kc_musl/linux-ramips_mt76x8/backports-5.10.42-1/.prepared_check
rm -rf /home/nikita/ohic/REPO/camera-debug-facility/tmp/openwrt-21.02.0/build_dir/target-mipsel_24kc_musl/linux-ramips_mt76x8/backports-5.10.42-1
mkdir -p /home/nikita/ohic/REPO/camera-debug-facility/tmp/openwrt-21.02.0/build_dir/target-mipsel_24kc_musl/linux-ramips_mt76x8/backports-5.10.42-1
. /home/nikita/ohic/REPO/camera-debug-facility/tmp/openwrt-21.02.0/include/shell.sh; xzcat /home/nikita/ohic/REPO/camera-debug-facility/tmp/openwrt-21.02.0/dl/backports-5.10.42-1.tar.xz | tar -C /home/nikita/ohic/REPO/camera-debug-facility/tmp/openwrt-21.02.0/build_dir/target-mipsel_24kc_musl/linux-ramips_mt76x8/backports-5.10.42-1/.. -xf -
rm -rf /home/nikita/ohic/REPO/camera-debug-facility/tmp/openwrt-21.02.0/build_dir/target-mipsel_24kc_musl/linux-ramips_mt76x8/backports-5.10.42-1/patches; mkdir -p /home/nikita/ohic/REPO/camera-debug-facility/tmp/openwrt-21.02.0/build_dir/target-mipsel_24kc_musl/linux-ramips_mt76x8/backports-5.10.42-1/patches
touch /home/nikita/ohic/REPO/camera-debug-facility/tmp/openwrt-21.02.0/build_dir/target-mipsel_24kc_musl/linux-ramips_mt76x8/backports-5.10.42-1/.quilt_used
tar -C /home/nikita/ohic/REPO/camera-debug-facility/tmp/openwrt-21.02.0/build_dir/target-mipsel_24kc_musl/linux-ramips_mt76x8/backports-5.10.42-1 -xzf /home/nikita/ohic/REPO/camera-debug-facility/tmp/openwrt-21.02.0/dl/ipw2100-fw-1.3.tgz
tar -C /home/nikita/ohic/REPO/camera-debug-facility/tmp/openwrt-21.02.0/build_dir/target-mipsel_24kc_musl/linux-ramips_mt76x8/backports-5.10.42-1 -xzf /home/nikita/ohic/REPO/camera-debug-facility/tmp/openwrt-21.02.0/dl/ipw2200-fw-3.1.tgz
tar -C /home/nikita/ohic/REPO/camera-debug-facility/tmp/openwrt-21.02.0/build_dir/target-mipsel_24kc_musl/linux-ramips_mt76x8/backports-5.10.42-1 -xjf /home/nikita/ohic/REPO/camera-debug-facility/tmp/openwrt-21.02.0/dl/zd1211-firmware-1.4.tar.bz2
rm -rf /home/nikita/ohic/REPO/camera-debug-facility/tmp/openwrt-21.02.0/build_dir/target-mipsel_24kc_musl/linux-ramips_mt76x8/backports-5.10.42-1/include/linux/ssb /home/nikita/ohic/REPO/camera-debug-facility/tmp/openwrt-21.02.0/build_dir/target-mipsel_24kc_musl/linux-ramips_mt76x8/backports-5.10.42-1/include/linux/bcma /home/nikita/ohic/REPO/camera-debug-facility/tmp/openwrt-21.02.0/build_dir/target-mipsel_24kc_musl/linux-ramips_mt76x8/backports-5.10.42-1/include/net/bluetooth
rm -f /home/nikita/ohic/REPO/camera-debug-facility/tmp/openwrt-21.02.0/build_dir/target-mipsel_24kc_musl/linux-ramips_mt76x8/backports-5.10.42-1/include/linux/cordic.h /home/nikita/ohic/REPO/camera-debug-facility/tmp/openwrt-21.02.0/build_dir/target-mipsel_24kc_musl/linux-ramips_mt76x8/backports-5.10.42-1/include/linux/crc8.h /home/nikita/ohic/REPO/camera-debug-facility/tmp/openwrt-21.02.0/build_dir/target-mipsel_24kc_musl/linux-ramips_mt76x8/backports-5.10.42-1/include/linux/eeprom_93cx6.h /home/nikita/ohic/REPO/camera-debug-facility/tmp/openwrt-21.02.0/build_dir/target-mipsel_24kc_musl/linux-ramips_mt76x8/backports-5.10.42-1/include/linux/wl12xx.h /home/nikita/ohic/REPO/camera-debug-facility/tmp/openwrt-21.02.0/build_dir/target-mipsel_24kc_musl/linux-ramips_mt76x8/backports-5.10.42-1/include/linux/spi/libertas_spi.h /home/nikita/ohic/REPO/camera-debug-facility/tmp/openwrt-21.02.0/build_dir/target-mipsel_24kc_musl/linux-ramips_mt76x8/backports-5.10.42-1/include/net/ieee80211.h /home/nikita/ohic/REPO/camera-debug-facility/tmp/openwrt-21.02.0/build_dir/target-mipsel_24kc_musl/linux-ramips_mt76x8/backports-5.10.42-1/backport-include/linux/bcm47xx_nvram.h
echo 'compat-wireless-5.10.42-1-1-r16279-5cc0535800' > /home/nikita/ohic/REPO/camera-debug-facility/tmp/openwrt-21.02.0/build_dir/target-mipsel_24kc_musl/linux-ramips_mt76x8/backports-5.10.42-1/compat_version
touch /home/nikita/ohic/REPO/camera-debug-facility/tmp/openwrt-21.02.0/build_dir/target-mipsel_24kc_musl/linux-ramips_mt76x8/backports-5.10.42-1/.prepared
make[2]: Leaving directory '/home/nikita/ohic/REPO/camera-debug-facility/tmp/openwrt-21.02.0/package/kernel/mac80211'
time: package/kernel/mac80211/prepare#1.34#0.35#1.55
make[1]: Leaving directory '/home/nikita/ohic/REPO/camera-debug-facility/tmp/openwrt-21.02.0'
```

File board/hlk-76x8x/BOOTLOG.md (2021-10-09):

# Factory boot log

```console
nikita@nikita-System-Product-Name:/mnt/storage$ picocom -b 57600 /dev/ttyUSB0
picocom v3.1

port is        : /dev/ttyUSB0
flowcontrol    : none
baudrate is    : 57600
parity is      : none
databits are   : 8
stopbits are   : 1
escape is      : C-a
local echo is  : no
noinit is      : no
noreset is     : no
hangup is      : no
nolock is      : no
send_cmd is    : sz -vv
receive_cmd is : rz -vv -E
imap is        : 
omap is        : 
emap is        : crcrlf,delbs,
logfile is     : none
initstring     : none
exit_after is  : not set
exit is        : no

Type [C-a] [C-h] to see available commands
Terminal ready
flash manufacture id: ef, device id 40 19
info id : ef info->jedec_id :40160000 buf[1]:40 buf[2]:19
info id : ef info->jedec_id :40170000 buf[1]:40 buf[2]:19
info id : ef info->jedec_id :40180000 buf[1]:40 buf[2]:19
info id : ef info->jedec_id :40190000 buf[1]:40 buf[2]:19
find flash: W25Q256FV
*** Warning - bad CRC, using default environment

============================================ 
Ralink UBoot Version: 1.0
-------------------------------------------- 
ASIC 7628_MP (Port5<->None)
DRAM component: 1024 Mbits DDR, width 16
DRAM bus: 16 bit
Total memory: 128 MBytes
Flash component: SPI Flash
Date:May 23 2020  Time:14:42:28
============================================ 
icache: sets:512, ways:4, linesz:32 ,total:65536
dcache: sets:256, ways:4, linesz:32 ,total:32768 
RESET MT7628 PHY!!!!!!

  _    _   _        _  __  ______     __    ___     ___    _   _   
 | |  | | | |      | |/ / |____  |   / /   |__ \   / _ \  | \ | |  
 | |__| | | |      | ' /      / /   / /_      ) | | (_) | |  \| |  
 |  __  | | |      |  <      / /   | '_ \    / /   > _ <  | . ` |  
 | |  | | | |____  | . \    / /    | (_) |  / /_  | (_) | | |\  |  
 |_|  |_| |______| |_|\_\  /_/      \___/  |____|  \___/  |_| \_|  
-------------------------------------------------------------------------
             https://github.com/gnubee-git
-------------7628N build May 23 2020 14:42:28--------------------
-------------------------------------------------------------------------

Please choose the operation: 
   1: Load system code to SDRAM via TFTP. 
   2: Load system code then write to Flash via TFTP. 
   3: Boot system code via Flash (default).
   4: Entr boot command line interface.
   5: Load system code then write to Flash via Httpd.
   7: Load Boot Loader code then write to Flash via Serial. 
   9: Load Boot Loader code then write to Flash via TFTP. 
 0 
   
3: System Boot system code via Flash.
## Booting image at bc050000 ...
   Image Name:   OpenWrt Linux-3.10.14
   Image Type:   MIPS Linux Kernel Image (lzma compressed)
   Data Size:    1274036 Bytes =  1.2 MB
   Load Address: 80000000
   Entry Point:  80000000
   Verifying Checksum ... OK
   Uncompressing Kernel Image ... OK
No initrd
## Transferring control to Linux (at address 80000000) ...
## Giving linux memsize in MB, 128

Starting kernel ...

LINUX started...

 THIS IS ASIC

SDK 5.0.S.0
[    0.000000] Linux version 3.10.14 (luke@ub) (gcc version 4.8.3 (OpenWrt/Linaro GCC 4.8-2014.04 unknown) ) #5 Sat May 23 11:56:08 CST 2020
[    0.000000] 
[    0.000000]  The CPU feqenuce set to 575 MHz
[    0.000000] CPU0 revision is: 00019655 (MIPS 24KEc)
[    0.000000] Software DMA cache coherency
[    0.000000] Determined physical RAM map:
[    0.000000]  memory: 08000000 @ 00000000 (usable)
[    0.000000] Initrd not found or empty - disabling initrd
[    0.000000] Zone ranges:
[    0.000000]   Normal   [mem 0x00000000-0x07ffffff]
[    0.000000] Movable zone start for each node
[    0.000000] Early memory node ranges
[    0.000000]   node   0: [mem 0x00000000-0x07ffffff]
[    0.000000] Primary instruction cache 64kB, 4-way, VIPT, linesize 32 bytes.
[    0.000000] Primary data cache 32kB, 4-way, PIPT, no aliases, linesize 32 bytes
[    0.000000] Built 1 zonelists in Zone order, mobility grouping on.  Total pages: 32512
[    0.000000] Kernel command line: console=ttyS1,57600n8 root=/dev/mtdblock5 rootfstype=squashfs,jffs2
[    0.000000] PID hash table entries: 512 (order: -1, 2048 bytes)
[    0.000000] Dentry cache hash table entries: 16384 (order: 4, 65536 bytes)
[    0.000000] Inode-cache hash table entries: 8192 (order: 3, 32768 bytes)
[    0.000000] Writing ErrCtl register=0000000f
[    0.000000] Readback ErrCtl register=0000000f
[    0.000000] Memory: 126060k/131072k available (2774k kernel code, 5012k reserved, 696k data, 176k init, 0k highmem)
[    0.000000] NR_IRQS:128
[    0.000000] console [ttyS1] enabled
[    0.096000] Calibrating delay loop... 382.46 BogoMIPS (lpj=764928)
[    0.128000] pid_max: default: 32768 minimum: 301
[    0.132000] Mount-cache hash table entries: 512
[    0.136000] NET: Registered protocol family 16
[    0.140000] RALINK_GPIOMODE = 54054404 
[    0.144000] RALINK_GPIOMODE = 54044404 
[    0.244000] ***** Xtal 40MHz *****
[    0.248000] start PCIe register access
[    0.748000] RALINK_RSTCTRL = 2400000
[    0.752000] RALINK_CLKCFG1 = fdbfffc0
[    0.756000] 
[    0.756000] *************** MT7628 PCIe RC mode *************
[    1.256000] PCIE0 no card, disable it(RST&CLK)
[    1.284000] bio: create slab <bio-0> at 0
[    1.288000] usbcore: registered new interface driver usbfs
[    1.292000] usbcore: registered new interface driver hub
[    1.296000] usbcore: registered new device driver usb
[    1.300000] Switching to clocksource MIPS
[    1.304000] NET: Registered protocol family 2
[    1.316000] TCP established hash table entries: 1024 (order: 1, 8192 bytes)
[    1.328000] TCP bind hash table entries: 1024 (order: 0, 4096 bytes)
[    1.340000] TCP: Hash tables configured (established 1024 bind 1024)
[    1.356000] TCP: reno registered
[    1.360000] UDP hash table entries: 256 (order: 0, 4096 bytes)
[    1.372000] UDP-Lite hash table entries: 256 (order: 0, 4096 bytes)
[    1.384000] NET: Registered protocol family 1
[    1.396000] MTK/Ralink EHCI/OHCI init.
[    1.404000] squashfs: version 4.0 (2009/01/31) Phillip Lougher
[    1.416000] jffs2: version 2.2. (NAND) (SUMMARY)  (LZMA) (RTIME) (CMODE_PRIORITY) (c) 2001-2006 Red Hat, Inc.
[    1.436000] msgmni has been set to 246
[    1.444000] io scheduler noop registered (default)
[    1.464000] Serial: 8250/16550 driver, 2 ports, IRQ sharing disabled
[    1.476000] serial8250: ttyS0 at MMIO 0x10000d00 (irq = 21) is a 16550A
[    1.488000] serial8250: ttyS1 at MMIO 0x10000c00 (irq = 20) is a 16550A
[    1.504000] Ralink gpio driver initialized
[    1.512000] flash manufacture id: ef, device id 40 19
[    1.524000] W25Q256FV(ef 40190000) (32768 Kbytes)
[    1.532000] mtd .name = raspi, .size = 0x02000000 (32M) .erasesize = 0x00010000 (64K) .numeraseregions = 0
[    1.552000] Creating 5 MTD partitions on "raspi":
[    1.564000] 0x000000000000-0x000002000000 : "ALL"
[    1.572000] 0x000000000000-0x000000030000 : "Bootloader"
[    1.584000] 0x000000030000-0x000000040000 : "Config"
[    1.596000] 0x000000040000-0x000000050000 : "Factory"
[    1.608000] 0x000000050000-0x000002000000 : "firmware"
[    1.620000] 0x0000001870f4-0x000002000000 : "rootfs"
[    1.632000] mtd: partition "rootfs" must either start or end on erase block boundary or be smaller than an erase block -- forcing read-only
[    1.656000] mtd: partition "rootfs_data" created automatically, ofs=0x490000, len=0x1b70000
[    1.672000] 0x000000490000-0x000002000000 : "rootfs_data"
[    1.688000] GMAC1_MAC_ADRH -- : 0x00004401
[    1.696000] GMAC1_MAC_ADRL -- : 0xbb89ee27
[    1.704000] Ralink APSoC Ethernet Driver Initilization. v3.1  512 rx/tx descriptors allocated, mtu = 1500!
[    1.720000] GMAC1_MAC_ADRH -- : 0x00004401
[    1.732000] GMAC1_MAC_ADRL -- : 0xbb89ee27
[    1.740000] PROC INIT OK!
[    1.744000] ehci_hcd: USB 2.0 'Enhanced' Host Controller (EHCI) Driver
[    1.756000] ehci-pci: EHCI PCI platform driver
[    1.768000] ehci-platform: EHCI generic platform driver
[    1.796000] ******MT7628 mtk phy
[    1.804000] *****run project phy.
[    1.820000] FM_OUT value: u4FmOut = 0(0x00000000)
[    1.836000] FM_OUT value: u4FmOut = 127(0x0000007F)
[    1.844000] FM detection done! loop = 1
[    1.860000] SR calibration value u1SrCalVal = 6
[    1.868000] *********Execute mt7628_phy_init!!
[    1.876000] ehci-platform ehci-platform: EHCI Host Controller
[    1.888000] ehci-platform ehci-platform: new USB bus registered, assigned bus number 1
[    1.904000] ehci-platform ehci-platform: irq 18, io mem 0x101c0000
[    1.928000] ehci-platform ehci-platform: USB 2.0 started, EHCI 1.00
[    1.940000] hub 1-0:1.0: USB hub found
[    1.948000] hub 1-0:1.0: 1 port detected
[    1.956000] ohci_hcd: USB 1.1 'Open' Host Controller (OHCI) Driver
[    1.988000] *********Execute mt7628_phy_init!!
[    1.996000] ohci-platform ohci-platform: Generic Platform OHCI Controller
[    2.012000] ohci-platform ohci-platform: new USB bus registered, assigned bus number 2
[    2.028000] ohci-platform ohci-platform: irq 18, io mem 0x101c1000
[    2.100000] hub 2-0:1.0: USB hub found
[    2.108000] hub 2-0:1.0: 1 port detected
[    2.116000] gre: GRE over IPv4 demultiplexor driver
[    2.124000] TCP: cubic registered
[    2.132000] NET: Registered protocol family 10
[    2.144000] NET: Registered protocol family 17
[    2.152000] 8021q: 802.1Q VLAN Support v1.8
[    2.160000] registered taskstats version 1
[    2.176000] VFS: Mounted root (squashfs filesystem) readonly on device 31:5.
[    2.192000] Freeing unused kernel memory: 176K (80364000 - 80390000)
procd: Console is alive
[    4.396000] SCSI subsystem initialized
[    4.412000] usbcore: registered new interface driver usb-storage
procd: - preinit -
[    5.376000] 44: 1:FFFFFFBB:FFFFFF89:FFFFFFEE:27
[    5.388000] Raeth v3.1 (Tasklet,SkbRecycle)
[    5.396000] 
[    5.396000] phy_tx_ring = 0x070ca000, tx_ring = 0xa70ca000
[    5.412000] 
[    5.412000] phy_rx_ring0 = 0x070cc000, rx_ring0 = 0xa70cc000
[    5.440000] GMAC1_MAC_ADRH -- : 0x00004401
[    5.448000] GMAC1_MAC_ADRL -- : 0xbb89ee27
[    5.456000] RT305x_ESW: Link Status Changed
Press the [f] key and hit [enter] to enter failsafe mode
Press the [1], [2], [3] or [4] key and hit [enter] to select the debug level
[    9.020000] block: attempting to load /etc/config/fstab
[    9.108000] block: extroot: not configured
uci: Entry not found
uci: Entry not found
OPTIMIZED_FOR -> wifi
NUM_OF_CPU -> 1
wifiDomain1 -> 
wifiDomain2 -> 
CONFIG_RALINK_MT7621 -[    9.332000] ra2880stop()...> 
CONFIG_ARCH_Done
MT7623 -> 
jffs[    9.344000] Free TX/RX Ring Memory!
2 is not ready - marker found
procd: - early -
procd: - ubus -
procd: - init -
Please press Enter to activate this console.
[   11.348000] u32 classifier
[   11.352000]     input device check on
[   11.360000]     Actions configured
[   11.392000] Mirror/redirect action on
[   11.436000] cfg80211: Calling CRDA to update world regulatory domain
[   11.452000] ip_tables: (C) 2000-2006 Netfilter Core Team
[   11.460000] Type=Linux
[   11.504000] nf_conntrack version 0.5.0 (1972 buckets, 7888 max)
[   11.540000] rdm_major = 253
[   11.588000] xt_time: kernel timezone is -0000
[   11.604000] PPP generic driver version 2.4.2
[   11.616000] NET: Registered protocol family 24
[   16.364000] 44: 1:FFFFFFBB:FFFFFF89:FFFFFFEE:27
[   16.372000] Raeth v3.1 (Tasklet,SkbRecycle)
[   16.384000] 
[   16.384000] phy_tx_ring = 0x072ea000, tx_ring = 0xa72ea000
[   16.400000] 
[   16.400000] phy_rx_ring0 = 0x072ec000, rx_ring0 = 0xa72ec000
[   16.428000] GMAC1_MAC_ADRH -- : 0x00004401
[   16.436000] GMAC1_MAC_ADRL -- : 0xbb89ee27
[   16.444000] RT305x_ESW: Link Status Changed
[   16.496000] device eth0.1 entered promiscuous mode
[   16.504000] device eth0 entered promiscuous mode
[   16.536000] br-lan: port 1(eth0.1) entered forwarding state
[   16.548000] br-lan: port 1(eth0.1) entered forwarding state
[   18.552000] br-lan: port 1(eth0.1) entered forwarding state
[   19.952000] 
[   19.952000] 
[   19.952000] === pAd = c08b7000, size = 1460128 ===
[   19.952000] 
[   19.968000] <-- RTMPAllocTxRxRingMemory, Status=0, ErrorValue=0x
[   19.984000] <-- RTMPAllocAdapterBlock, Status=0
[   19.992000] RtmpChipOpsHook(492): Not support for HIF_MT yet!
[   20.004000] mt7628_init()-->
[   20.008000] mt7628_init(FW(8a00), HW(8a01), CHIPID(7628))
[   20.020000] e2.bin mt7628_init(1117)::(2), pChipCap->fw_len(63056)
[   20.032000] mt_bcn_buf_init(218): Not support for HIF_MT yet!
[   20.044000] <--mt7628_init()
[   20.132000] TX_BCN DESC a6769000 size = 320
[   20.144000] RX[0] DESC a676b000 size = 2048
[   20.152000] RX[1] DESC a676c000 size = 1024
[   20.264000] E2pAccessMode=2
[   20.272000] cfg_mode=9
[   20.276000] cfg_mode=9
[   20.280000] wmode_band_equal(): Band Equal!
[   20.292000] APSDCapable[0]=1
[   20.300000] APSDCapable[1]=1
[   20.304000] APSDCapable[2]=1
[   20.308000] APSDCapable[3]=1
[   20.316000] APSDCapable[4]=1
[   20.320000] APSDCapable[5]=1
[   20.328000] APSDCapable[6]=1
[   20.332000] APSDCapable[7]=1
[   20.340000] APSDCapable[8]=1
[   20.344000] APSDCapable[9]=1
[   20.352000] APSDCapable[10]=1
[   20.356000] APSDCapable[11]=1
[   20.360000] APSDCapable[12]=1
[   20.368000] APSDCapable[13]=1
[   20.372000] APSDCapable[14]=1
[   20.380000] APSDCapable[15]=1
[   20.384000] default ApCliAPSDCapable[0]=1
[   20.392000] default ApCliAPSDCapable[1]=1
[   20.600000] Key1Str is Invalid key length(0) or Type(0)
[   20.612000] Key2Str is Invalid key length(0) or Type(0)
[   20.624000] Key3Str is Invalid key length(0) or Type(0)
[   20.636000] Key4Str is Invalid key length(0) or Type(0)
[   20.700000] RTMPSetDefaultChannel() : default channel to 1 
[   20.712000] load fw image from fw_header_image
[   20.720000] AndesMTLoadFwMethod1(2174)::pChipCap->fw_len(63056)
[   20.732000] FW Version:_e2_mp
[   20.740000] FW Build Date:20150211175503
[   20.748000] CmdAddressLenReq:(ret = 0)
[   20.756000] CmdFwStartReq: override = 1, address = 1048576
[   20.768000] CmdStartDLRsp: WiFI FW Download Success
[   21.112000] MtAsicDMASchedulerInit(): DMA Scheduler Mode=0(LMAC)
[   21.124000] efuse_probe: efuse = 10000012
[   21.132000] RtmpChipOpsEepromHook::e2p_type=2, inf_Type=4
[   21.140000] RtmpEepromGetDefault::e2p_dafault=2
[   21.148000] RtmpChipOpsEepromHook: E2P type(2), E2pAccessMode = 2, E2P default = 2
[   21.164000] NVM is FLASH mode
[   21.172000] 1. Phy Mode = 14
[   21.344000] Country Region from e2p = ffff
[   21.356000] tssi_1_target_pwr_g_band = 31
[   21.364000] 2. Phy Mode = 14
[   21.368000] 3. Phy Mode = 14
[   21.372000] NICInitPwrPinCfg(11): Not support for HIF_MT yet!
[   21.384000] NICInitializeAsic(651): Not support rtmp_mac_sys_reset () for HIF_MT yet!
[   21.400000] mt_mac_init()-->
[   21.408000] MtAsicInitMac()-->
[   21.416000] mt7628_init_mac_cr()-->
[   21.420000] MtAsicSetMacMaxLen(1241): Set the Max RxPktLen=1024!
[   21.432000] <--mt_mac_init()
[   21.440000] 	WTBL Segment 1 info:
[   21.444000] 		MemBaseAddr/FID:0x28000/0
[   21.452000] 		EntrySize/Cnt:32/128
[   21.460000] 	WTBL Segment 2 info:
[   21.468000] 		MemBaseAddr/FID:0x40000/0
[   21.476000] 		EntrySize/Cnt:64/128
[   21.480000] 	WTBL Segment 3 info:
[   21.488000] 		MemBaseAddr/FID:0x42000/64
[   21.496000] 		EntrySize/Cnt:64/128
[   21.504000] 	WTBL Segment 4 info:
[   21.508000] 		MemBaseAddr/FID:0x44000/128
[   21.516000] 		EntrySize/Cnt:32/128
[   21.524000] AntCfgInit(2876): Not support for HIF_MT yet!
[   21.672000] CmdSlotTimeSet:(ret = 0)
[   21.784000] MCS Set = ff ff 00 00 01
[   21.788000] MtAsicSetChBusyStat(826): Not support for HIF_MT yet!
[   24.820000] [PMF]ap_pmf_init:: apidx=0, MFPC=0, MFPR=0, SHA256=0
[   24.832000] [PMF]RTMPMakeRsnIeCap: RSNIE Capability MFPC=0, MFPR=0
[   24.848000] MtAsicSetRalinkBurstMode(2919): Not support for HIF_MT yet!
[   24.860000] MtAsicSetPiggyBack(763): Not support for HIF_MT yet!
[   24.924000] MtAsicSetTxPreamble(2898): Not support for HIF_MT yet!
[   24.940000] MtAsicAddSharedKeyEntry(1308): Not support for HIF_MT yet!
[   24.952000] The 4-BSSID mode is enabled, the BSSID byte5 MUST be the multiple of 4
[   24.968000] MtAsicSetPreTbtt(): bss_idx=0, PreTBTT timeout = 0xf0
[   24.980000] Main bssid = 44:01:bb:89:ee:26
[   24.988000] <==== rt28xx_init, Status=0
[   25.020000] RT28xx_Monitor_Init: 764 !!!!####!!!!!!
[   25.032000] mt7628_set_ed_cca: TURN OFF EDCCA  mac 0x10618 = 0xd7083f0f
[   25.048000] WiFi Startup Cost (ra0): 4.916s
[   26.584000] device ra0 entered promiscuous mode
[   26.596000] br-lan: port 2(ra0) entered forwarding state
[   26.604000] br-lan: port 2(ra0) entered forwarding state
[   27.732000] jffs2_scan_eraseblock(): End of filesystem marker found at 0x0
[   27.752000] jffs2_build_filesystem(): unlocking the mtd device... done.
[   27.764000] jffs2_build_filesystem(): erasing all blocks after the end marker... [   28.608000] br-lan: port 2(ra0) entered forwarding state

BusyBox v1.22.1 (2020-05-22 17:37:32 CST) built-in shell (ash)
Enter 'help' for a list of built-in commands.

  _______                     ________        __
 |       |.-----.-----.-----.|  |  |  |.----.|  |_
 |   -   ||  _  |  -__|     ||  |  |  ||   _||   _|
 |_______||   __|_____|__|__||________||__|  |____|
          |__| W I R E L E S S   F R E E D O M
 -----------------------------------------------------
 BARRIER BREAKER (Barrier Breaker, unknown)
 -----------------------------------------------------
  * 1/2 oz Galliano         Pour all ingredients into
  * 4 oz cold Coffee        an irish coffee mug filled
  * 1 1/2 oz Dark Rum       with crushed ice. Stir.
  * 2 tsp. Creme de Cacao
 -----------------------------------------------------
root@OpenWrt:/# 
root@OpenWrt:/# 
root@OpenWrt:/# 
```

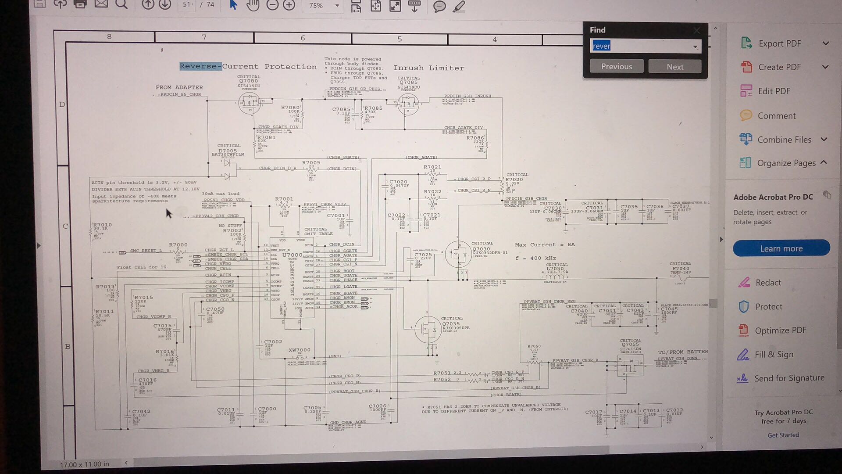
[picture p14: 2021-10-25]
hardware/references/reverse-over-voltage-protection/MacBook.jpeg

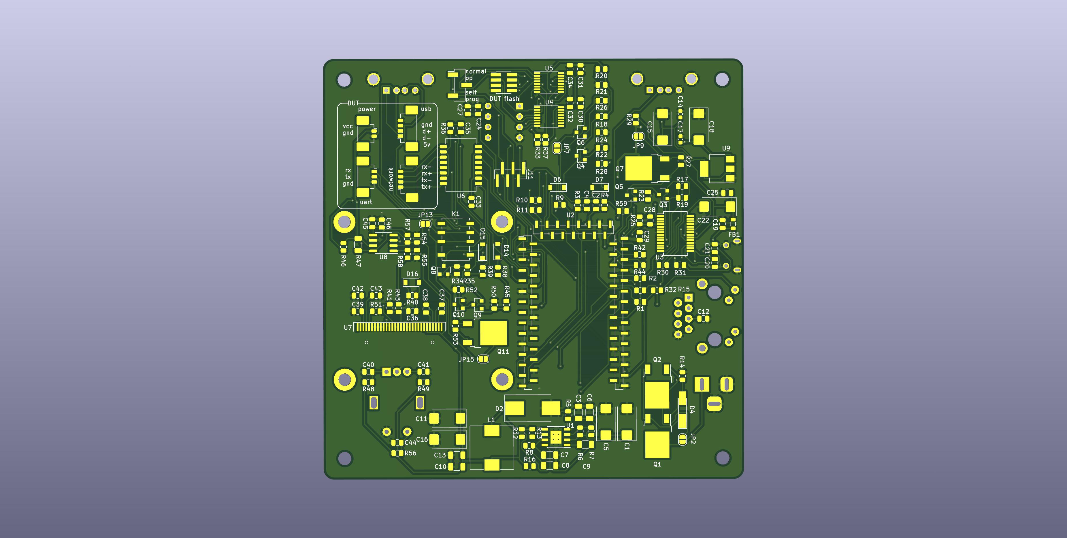
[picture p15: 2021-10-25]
hardware/cdf-1/cdf-1-back.jpg

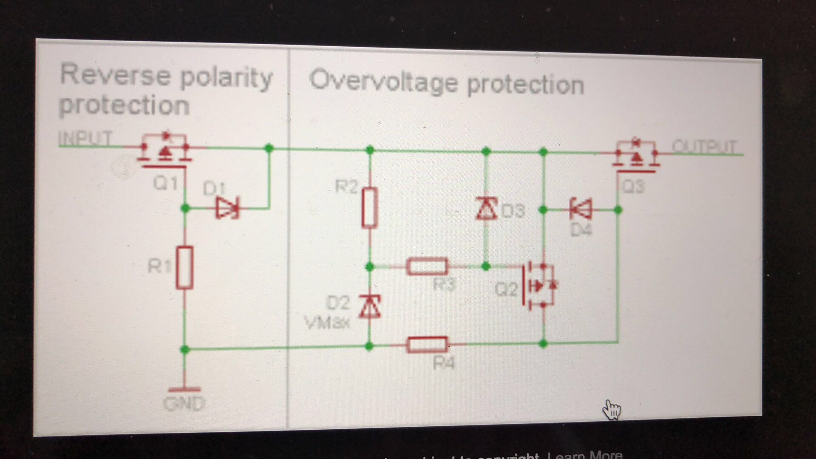
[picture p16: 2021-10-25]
hardware/references/reverse-over-voltage-protection/Reverse+Over-Voltage-Protection.jpeg

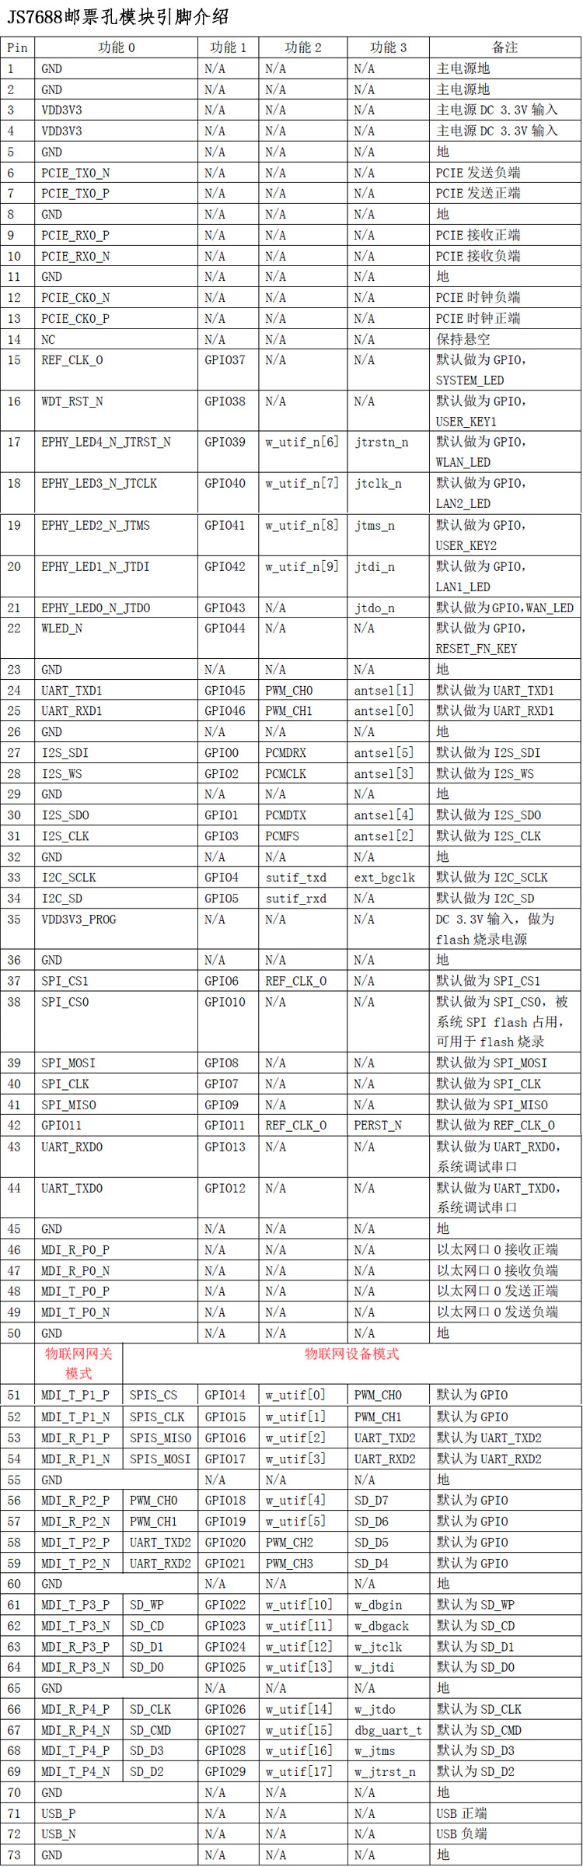
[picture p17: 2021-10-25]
board/js7688/pinout.jpg

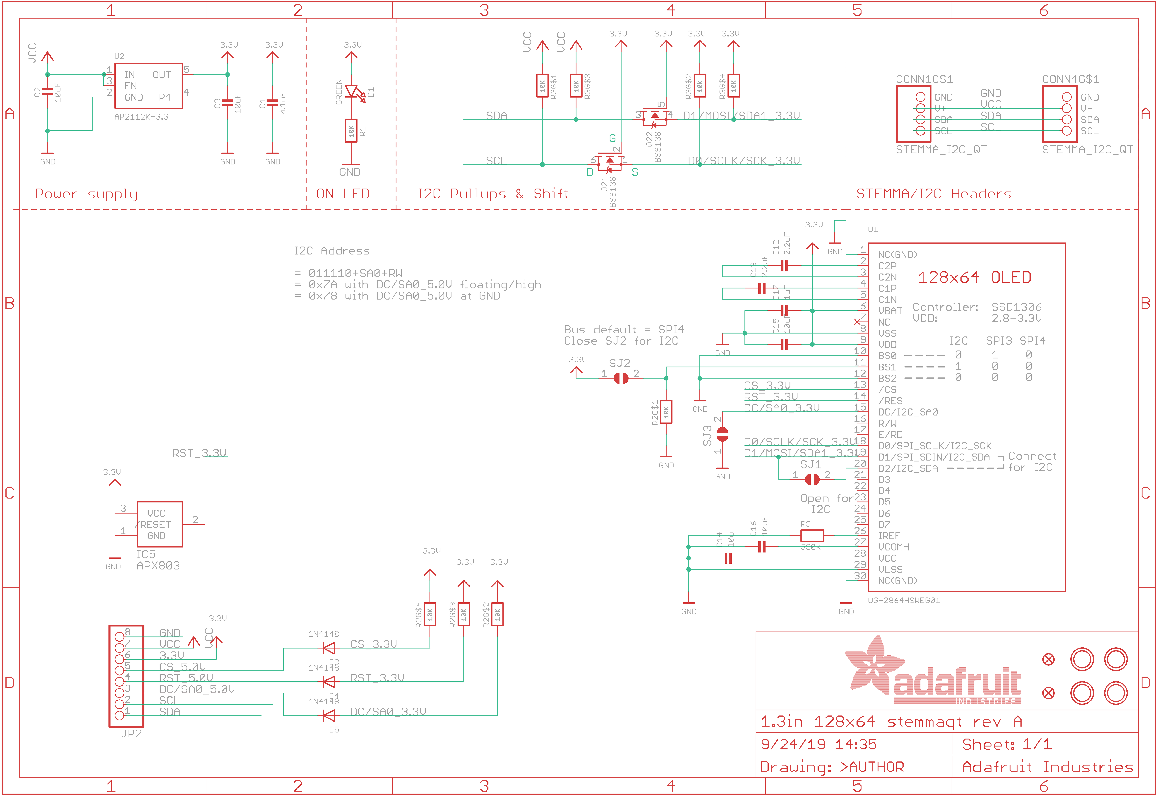
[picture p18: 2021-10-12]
hardware/references/adafruit_products_1-3_STEMMA_OLED_sch.png

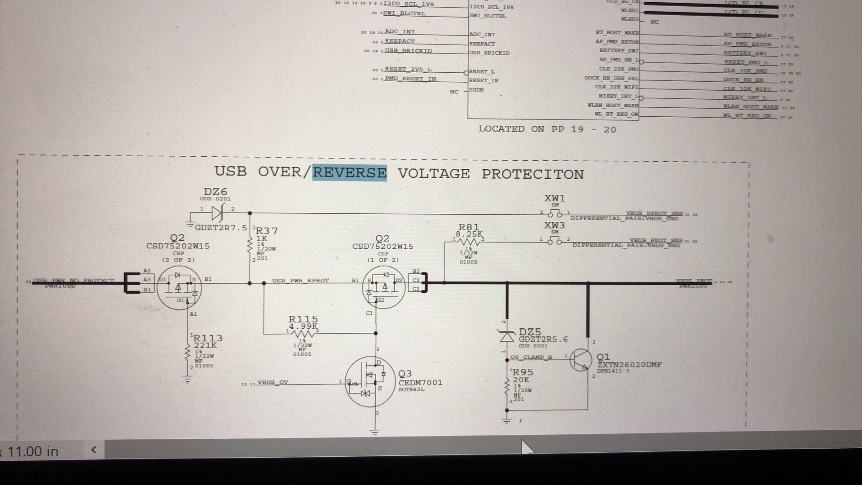
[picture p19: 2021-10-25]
hardware/references/reverse-over-voltage-protection/iPhone.jpeg

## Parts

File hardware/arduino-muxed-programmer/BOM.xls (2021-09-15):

Comment | Description | Designator | Quantity
0.01uF 10% 50V X7R | SMD 0805 Capacitor | C1, C3 | 2
0.1uF 10% 50V X7R | SMD 0805 Capacitor | C2, C4, C5 | 3
CL21B475KOFNFNE | CAP CER 0805 4.7µF ±10% 25V X7R | C6, C7, C8, C9, C10, C11, C12, C13 | 8
MAX40200AUK+T |  | DA1, DA2 | 2
SN74CB3Q3257PW | TSSOP | DD1, DD2 | 2
74HC541APW |  | DD3 | 1
ZIP DIP 16 | 3M™ Textool™.100” (2.54 mm) DIP Sockets ZIP DIP | J1 | 1
PLS-3 |  | J2 | 1
PLS-4 |  | J3 | 1
10k 5% | SMD 0805 Resistor | R1, R2, R3, R4 | 4
TSM-106-01-L-SV | TERMINAL STRIP 2.54mm 6X1P SMD Vertical | TB1, TB2 | 2
TSM-106-01-L-SV | TERMINAL STRIP 2.54mm 6X1P SMD Vertical | TB3, TB4, TB7, TB8 | 4
TSM-106-01-L-SV | TERMINAL STRIP 2.54mm 6X1P SMD Vertical | TB5, TB6 | 2
PLD-10 | TERMINAL STRIP 2.54mm 5X2P DIP Vertical | TB9 | 1
TSM | TERMINAL STRIP 1.27mm 5X2P DIP Vertical | TB10 | 1
PLLD-10 | TERMINAL STRIP 1.27mm 4X2P DIP Vertical | TB11 | 1

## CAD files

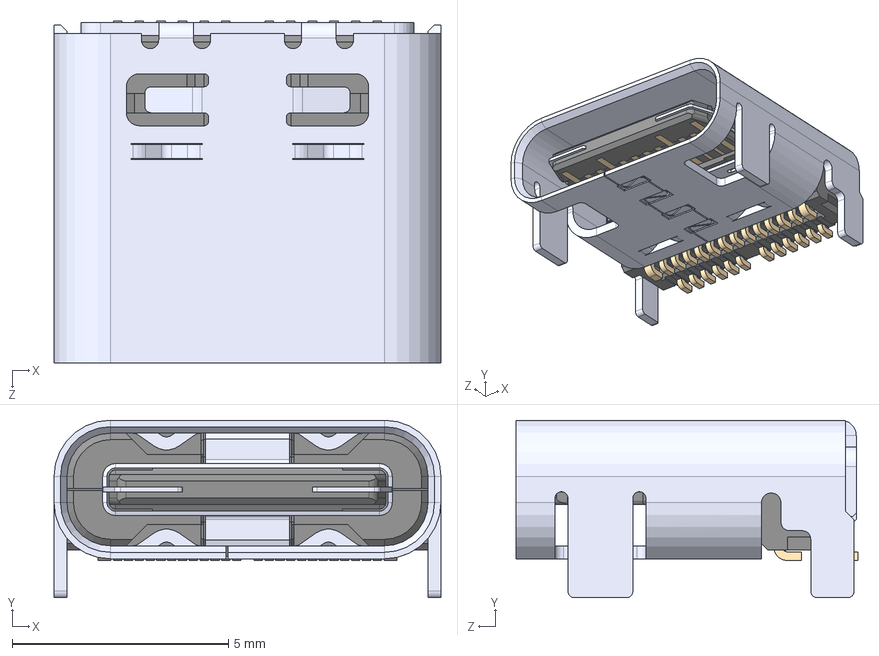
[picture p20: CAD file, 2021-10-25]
hardware/cdf-1/molex_105450-0101/105450-0101.step
8.94 x 4.10 x 7.90 mm

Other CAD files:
board/wms-76x8/WMS-7628N封装尺寸.DWG

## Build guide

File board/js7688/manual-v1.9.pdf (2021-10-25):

《JS76x8 开发板使用手册》 杭州卓钛科技有限公司 www.jotale.com

## JS76x8 开发板使用手册 v1.9(2021.01.16)

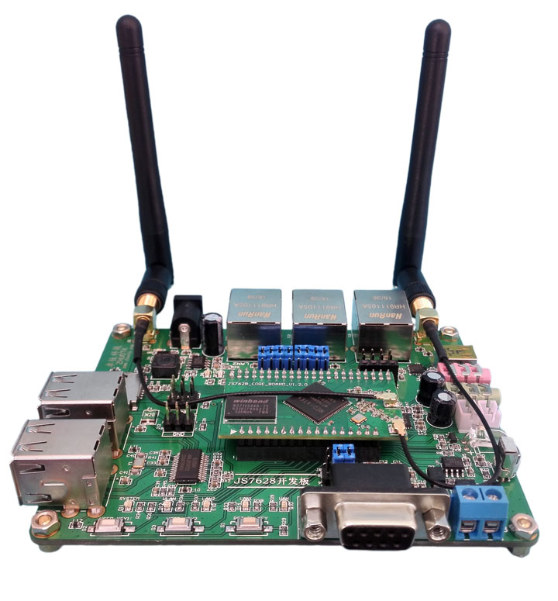
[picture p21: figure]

## 杭州卓钛科技有限公司

## 网站：www.jotale.com

目录

## 1. 开发板介绍

## 1.1 开发板概述

JS76x8 开发板包括 JS7688、JS7628、ZTK7628P 这三款板子,它们共用 JS76x8 底板。 JS76x8 开发板是杭州卓钛科技有限公司开发的基于 MTK（联发科）MT76x8 系列（MT7688AN、 MT7628AN/NN、MT7628DAN）SOC 芯片方案的学习开发评估板。本开发板的系统采用 openwrt(linux)源码完全开放，板子功能丰富，同时提供嵌入式 linux 学习资料、openwrt 学习资料，是学习嵌入式 linux、openwrt、物联网、DIY 智能家居网关、企业前期产品评估 的理想选择。JS7628 开发板包含一个底板（JS7628 底板）和一个核心板 JS7628 核心板（有 关该核心板的介绍，请看《JS7628 核心板介绍手册》）。

## 1.2 芯片简介

MT7628 是联发科技 2014 年底发布的业界新一代 2T2R 802.11n Wi-Fi AP/路由器系统单 芯片解决方案(SoC)。这款全新 SoC 为智能家庭内的数据、语音和影像应用程序提供高数据 传输率，而且耗电量远低于目前市场上其他同类产品。它和 MT7620 一样具有 2T2R 300M wifi 速率，接口丰富，但是它比 MT7620 功耗更低、芯片成本更低，专门针对物联网应用推出 3 个串口、PWM 输出等特点，可谓是 MT7620（2012 年发布）的升级产品。MT7628 和同年发布 的 MT7688（150M wifi）是同一类芯片，两者管脚、软件几乎完全兼容。

## 1.3 开发板特性

1) 580MHz 系统主频
2) 64MB/128MB/256MB DDR2 RAM
3) 8MB/16MB/32MB SPI nor flash
4) 无线协议 802.11 b/g/n,2T2R,最高 300Mbps 高速无线 wifi 传输速率
5) 3 个 100/10Mbps 支持自动翻转的 LAN/WAN 以太网口
6) 4 路标准的高速 USB 2.0 host 接口（支持 U 盘、USB 转串口线、USB 摄像头、USB 移动 硬盘、USB 3G/4G 网卡、USB 鼠标、USB 键盘、USB 无线网卡等超多 USB 外设）
7) 1 路 TTL/RS232 串口，1 路 TTL/485 串口，1 路 usb mini 调试串口
8) 5 个可配置 LED 普通网络/系统指示灯，4 路 PWM LED 灯（可实现 LED 调光功能）
9) 4 个可配置功能按键
10) 1 个 micro sd/TF 卡接口，(可插 micro sd/TF 卡实现大容量存储）
11) 1 路音频输出，1 路音频输入接口（可以播放 24bit 高品质 hifi 音乐）
12) 1 路红外接收，1 路红外发射
13) 15 路功能复用的 GPIO 口（核心板总共有 30 个 GPIO 口）
14) DC 5V 电源输入， 2.54mm 排针接口输出 5V、3.3V
15) 整机静态功耗仅 1W，芯片发热量很低
16) 支持路由、AP、中继、桥接等模式
17) 系统采用基于 linux 的 openwrt 开源操作系统，可用于智能家居网关、IP camera、VOIP、 遥控拍摄飞行器、远程监控系统、便携式 4G 路由器、音频对讲、简单的 WEB 网络服务 器、简单的 FTP 服务器、远程下载、遥控视觉小车等超多高级应用

## 1.4 开发板硬件资源

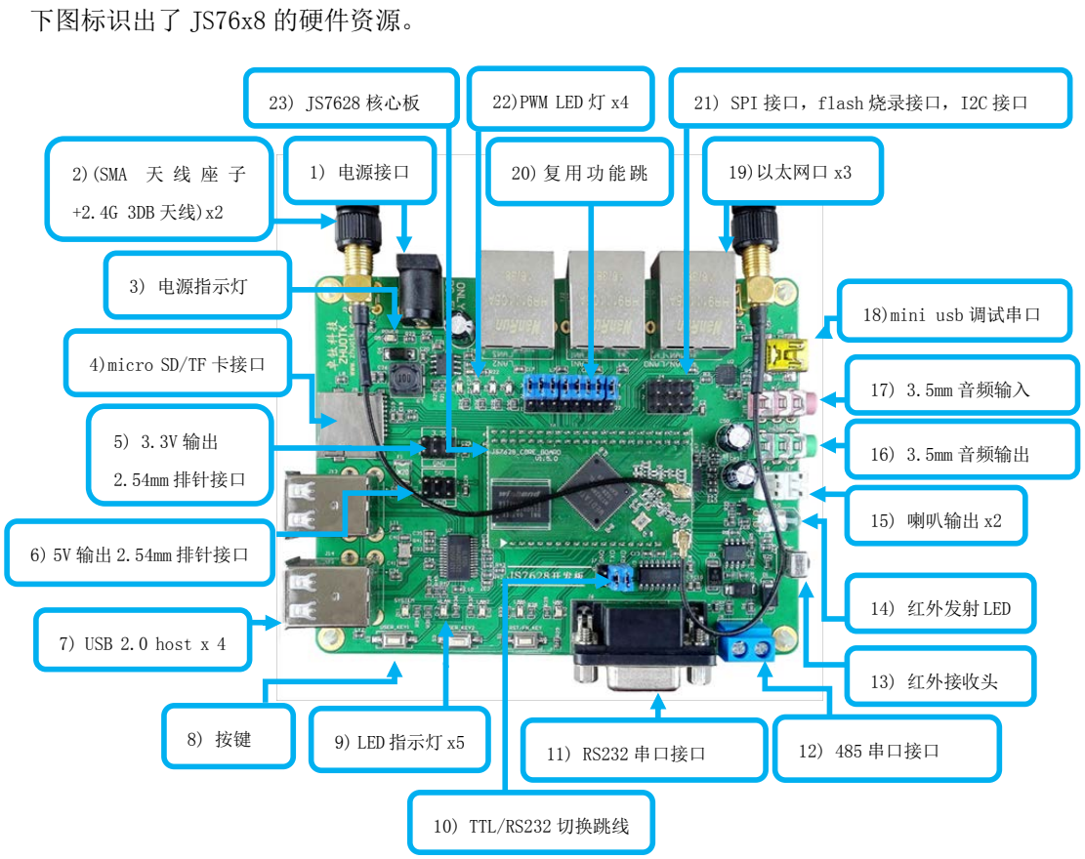
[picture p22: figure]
下图标识出了 JS76x8 的硬件资源。; 1) 电源接口; 3) 电源指示灯; 7) USB 2.0 host x 4; 2)(SMA 天线座子; 4)micro SD/TF 卡接口; 13) 红外接收头; 16) 3.5mm 音频输出; 17) 3.5mm 音频输入; 18)mini usb 调试串口; 15) 喇叭输出 x2; 2.54mm 排针接口; 14) 红外发射 LED; 6) 5V 输出 2.54mm 排针接口; 20) 复用功能跳; 19)以太网口 x3; 10) TTL/RS232 切换跳线; 22)PWM LED 灯 x4

1) 电源接口
请务必采用 DC 5V 电源，因用错电源导致开发板损坏的情况，不属于保修范围！尽 量采用开发板自带的 DC 5V 2A 电源。
2) SMA 天线座子 x2,2.4G 3DBi 天线 x2
双天线具有 2T2R（双发双收） 300Mbps wifi 的高速效果，如果用户只需要单天线也 能正常工作，不过 wifi 速率会受影响，只能实现 1T1R（单发单收）的功能。
3) 电源指示灯

### 4) micro SD/TF 卡接口

可以用于拓展存储空间，存储图片、音视频、安装超大程序等功能。

### 5) 3.3V 输出，2.54mm 排针接口

方便接其他 3.3V DC 供电的模块，不需要再另外配一个 3.3V 电源。双排针上排为正， 下排为地，读者也可以参考 PCB 上的丝印和底板原理图，切勿短接，或接错。

### 6) 5V 输出，2.54mm 排针接口

方便接其他 5V DC 供电的模块，不需要再另外配一个 5V 电源。双排针上排为正，下 排为地，读者也可以参考 PCB 上的丝印和底板原理图，切勿短接或反接。

### 7) USB 2.0 host x 4

4 个标准 USB 2.0 host 接口，可以接多个 USB 外设，比如 U 盘、USB 摄像头、USB 声 卡、USB 4G 网卡、USB 鼠标、USB 键盘等等，实现多种功能的自由组合。
8) 按键
从左到右依次是
a) “RST/FN_KEY”：复位/恢复出厂设置按键。开发板启动完成后，短按（范围小于
8) 按键 | 9) LED 指示灯 x5 | 11) RS232 串口接口 | 12) 485 串口接口
23) JS7628 核心板 | 21) SPI 接口，flash 烧录接口，I2C 接口

2s），开发板重启。长按（范围 5s~30s，一般 10s 左右），开发板恢复到出厂设 置。

### b) “USER_KEY2”：功能未定义，用户也可以参考《JS76x8 开发板 openwrt 入门教

程》中“添加修改按键功能”一节，自行配置按键功能。

### c) “USER_KEY1”：同上述。 9) LED 指示灯

从左到右依次是

### a) “system”：系统运行指示灯 b) “wlan”：wifi 通讯指示灯

c) “port2”：网口 2（PORT2）通讯指示灯，该网口有连接则灯亮起，有通讯则灯 闪烁。
d) “port1”：网口 1（PORT1）通讯指示灯，该网口有连接则灯亮起，有通讯则灯 闪烁。
e) “port0”：网口 0（PORT0）通讯指示灯，该网口有连接则灯亮起，有通讯则灯 闪烁。

### 10) TTL/RS232 切换跳线

如图，插上跳线帽，则启用 RS232 接口。拔掉跳线帽，则可接 3.3V TTL 串口。默认 跳线帽已插上。
11) RS232 串口接口
需按照 10）的说明启用该接口。串口 1，系统中的设备号是"/dev/ttyS1"
12) 485 串口接口
需按照 21）的说明启用该接口。串口 2，系统中的设备号是"/dev/ttyS2"
13) 红外接收头
开发板的提供相应的驱动和演示程序源码，具体用法请参考第章。
14) 红外发射 LED
开发板的提供相应的驱动和演示程序源码，具体用法请参考第章。
15) 喇叭输出
2 个 1W 喇叭左右声道输出，可以配合本店配套喇叭，实现声音外放功能。
16) 3.5mm 音频输出
标准通用的 3.5mm 接口，可以接普通耳机，音箱输入，支持 24bit 高品质 HIFI 音乐 播放，也可以实现通话功能（开发板教程有介绍）。
17) 3.5mm 音频输入
标准通用的 3.5mm 接口，可以接普通麦克风，支持录音、通话功能等功能（开发板教 程有介绍）。
18) mini usb 调试串口
开发板通过底板板载 USB 转串口芯片（CP2104），实现了核心板的调试串口转到 USB 接口功能。只需外接一根 mini USB 线，即可对开发板进行串口调试、下载程序。
19) 以太网口
从左到右依次是以太网口 PORT2、PORT1、PORT0，这 3 个网口默认是 LAN 口功能，读 者可以接任意一个，登录开发板的配置页面“192.168.1.251”。这 3 个网口也可配置 成为 WAN 口，实现普通路由器的 WAN 口功能，也可以实现多个 WAN 口多拨。
20) 复用功能跳线
由于 MT7628AN 芯片有两种模式“物联网网关”和“物联网设备”模式，这两种模式 下引脚可用功能的详见《JS76x8 核心板手册》。这两种功能主要区别就是对网口和其

他功能的复用，见下面原理图

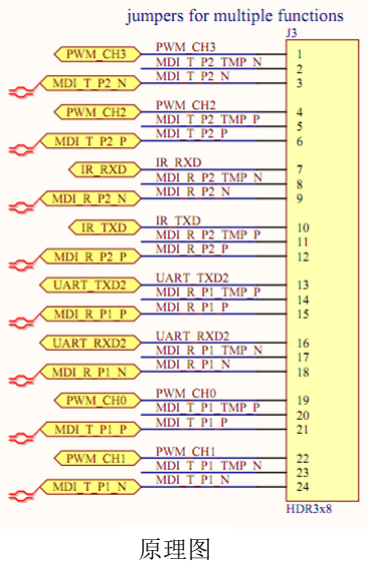
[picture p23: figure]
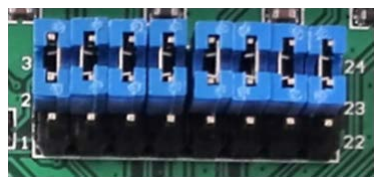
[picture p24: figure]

以上功能 3 个排针为一组，可以实现网口和 PWM、GPIO、UART2（TTL/485 串口）硬件 连接切换，并且需要配合相应的固件才能实现软件功能切换，请烧录资料中提供的相 应固件，读者可以查看资料里面带的 JS76x8 底板原理图，对照 PCB 上的丝印，以便 更清楚的了解。

21) SPI 接口，flash 烧录接口，I2C 接口

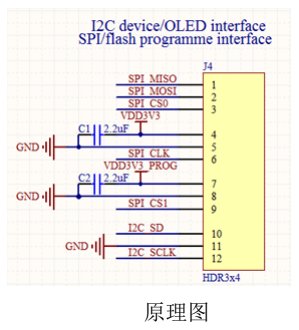
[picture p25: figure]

此接口引出了芯片的 SPI0、SPI1，由于 SPI0 被系统占用，用于读写 flash，不能做 其他应用。
读者可以查看资料里面带的 JS76x8 底板原理图，对照 PCB 上的丝印，以便更清楚的 了解。也可以接 I2C 通讯的模块传感器等。
22) PWM LED 灯
4 个可由 PWM 信号控制的 LED 灯
23) JS76x8 核心板
目前有
“8MB flash/64MB RAM”、“16MB flsh/128MB RAM”、“32MB flash/256MB RAM”
原理图 | 实物图
原理图 | 实物图

以上 3 种配置，如需单独购买请到 www.jotale.com (http://www.zhuotk.com/) 淘宝店铺进行购买。

## 1.5 开发板套件说明

JS76x8 开发板配套的配件如下表所示。
型号 | 数量 | 备注
JS76x8 底板 | 1 | 标配
JS76x8 核心板 | 1 | 标配
2 米以太网线 | 1 | 标配
Mini USB 数据线 | 1 | 标配
2.4G 3DBi 棒状天线 | 2（JS7628） 1（JS7688） 2（ZTK7628P） | 标配
5V 2A 电源 | 1 | 标配
开发板也可以选配 USB 声卡、USB 摄像头、红外遥控器、USB 4G 网卡、OLED 屏、传感器 等配件，可配合配套的教程实现更多高级的功能，如还未购买以上选配配件的读者可以到

### www.jotale.com 淘宝店铺中查看选购。

## 1.6 开发板配套资料说明

有关各个目录的内容介绍，请查看各文件夹下的“readme.txt”文件，这里不再赘述。

## 2. 开发板功能测试

## 2.1 基本功能测试

JS76x8 开发板出厂时已烧写完整的 openwrt 系统，用户完全可以将本开发板当成普通 路由器来使用。本节主要介绍开发板的路由器功能。

## 2.1.1 开机测试

1) 将开发板配套的 5V 电源插到开发板的电源接口，给开发板上电，电源“POWER”
| 指示灯立刻亮起（如果未亮起，请检查电源是否接好）。
2) 接着“WLAN”指示灯亮起，表示系统正在进入 uboot 启动。
3) 大约 15 秒后，系统运行 “SYSTEM” 指示灯快速闪烁，表示系统正在进入 openwrt
| 启动，大约 30 秒后“SYSTEM” 指示灯进入慢闪状态，表示系统已经启动完成。
4) 用网线将开发板 3 个网口中的任意一个网口和电脑直接相连（电脑需要采用自动
| 获取 IP 的方式或者设置静态 IP 为 192.168.1.xxx），此时开发板上 LAN 指示有闪 烁表示有数据通讯。在网页中输入开发板默认 IP 地址“192.168.1.251”，即可进 入开发板配置界面，如下所示。

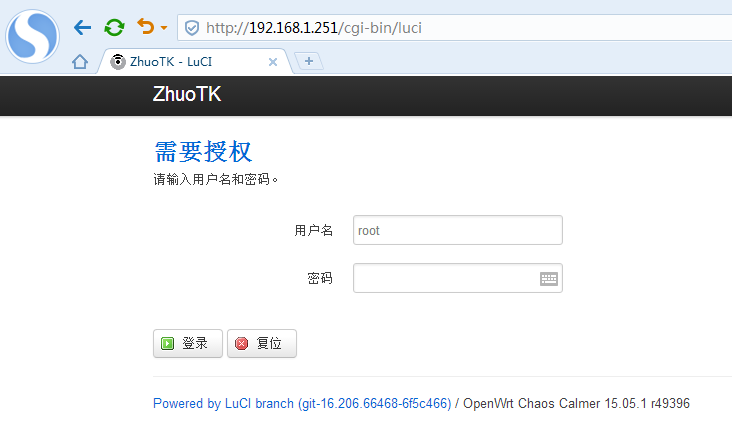
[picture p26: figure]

提示：如果需要读者需要将开发板通过路由器连接到局域网中，而非开发板直接 和电脑连接，则需要保证局域网的 IP 网段和开发板的 IP 网段一致，即 “192.168.1.*”，然后通过网线将开发板的任意一个网口和上级路由器的 LAN 口 连接即可，通过这种方式也可以访问开发板配置页面。开发板默认开启 DHCP，可 能会与现有局域网网关的 DHCP 功能相冲突，请根据情况开启关闭）。

注意：如无法登录开发板配置页面，请检查网线是否插好，电脑和开发板 IP 网段 的一致。

网页登录的用户名和密码，默认都是 root。输入完成后，点击“登录”即可进入 系统配置页面。如下图所示。

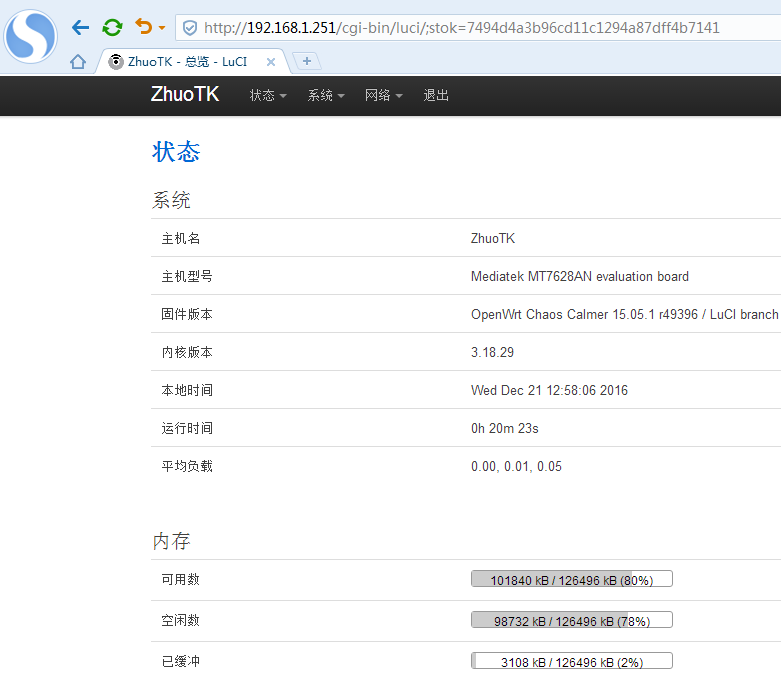
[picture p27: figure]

至此，开机测试完成。

## 2.1.2 wifi 测试

开发板出厂时默认开启 wifi，wifi 名为“Jotale_xxxx”,未加密。笔记本或手机可以 直接连接该名称的 wifi。如果已经将开发板连接到有互联网的网络中，连接 wifi 后， 设备即可上网。可点击 openwrt 系统配置页面的顶部菜单栏的“网络”->“无线”-> “修改”可对 wifi 加密、名称等进行配置。如下图

## 2.1.3 安装 tftp server(可选)

安装包在“JS76x8 开发板配套资料\开发工具软件\TFTP_Server.rar”。安装完成后双击图

标 | ，开启 tftp 服务器。
在对其进行配置前，需关闭 TFTP 功能，点击 | ，使其变成 | ，然后点击
进行服务器配置。
读者需要根据实际情况将下图所示的“Output directory”设置为 openwrt 固件 所在目录。

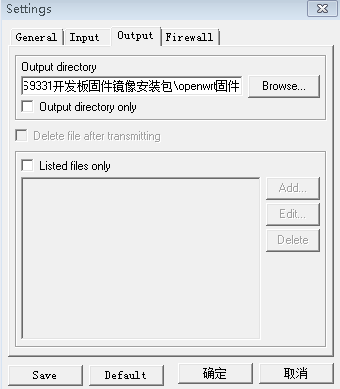
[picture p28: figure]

然后点击，“确定”，重新点击 | 使其变成 | 启动 tftp 服务器。

## 2.2 调试串口测试

## 2.2.1 安装 SecureCRT

为了实现开发板的串口调试，我们需要安装串口调试软件，常见的串口调试软件有 sscom32、超级终端、串口调试助手、SecureCRT 等。这里我们选择功能比较强大的 SecureCRT ，它支持 SSH1，SSH2，Telnet，RLogin，Serial 和 TAPI 协议，界面也很友好。 软件在开发板资料目录“JS9331 开发板配套资料/开发工具/VanDyke.SecureCRT.zip”，请 读者自行根据里面的提示进行安装。

## 安装 Putty(可选)

Putty 和 SecureCRT 一样具有 ssh、telnet、serial 等功能，但是它功能更为精简，无 需安装即可使用，请读者自行选择。
读者可以在“JS76x8 开发板配套资料\开发工具软件\putty_V0.63.0.0.43510830.exe” 找到。

## 2.2.2 安装调试串口驱动并打开调试串口

开发板上板载了 USB 转串口系统（采用 CP2104 芯片），用于串口调试。具体测试步骤如 下
1) 用开发板配套的 mini usb 线将开发板的 mini usb 接口和电脑的 USB 接口连接，此时电 脑需要安装了相应驱动，开发板的串口才能被电脑正确的识别。如果电脑无法识别串口， 请读者在“JS76x8 开发板配套资料\开发工具软\CP210x_VCP_Windows.zip”找到驱动

安装包并自行安装。电脑正确识别开发板的该串口后，在电脑的“设备管理器”->“端 口”下会出现类似下图（作者用的是 win7）

注：上图中的“COM87”是作者电脑上的串口号，读者的电脑上的串口号可能会有所不同， 请自行查看。
2) 打开之前安装的 SecureCRT，如下图所示。

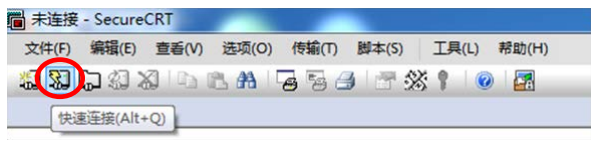
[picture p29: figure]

点击上图所示的红圈按钮所标的“快速连接”，出现下图

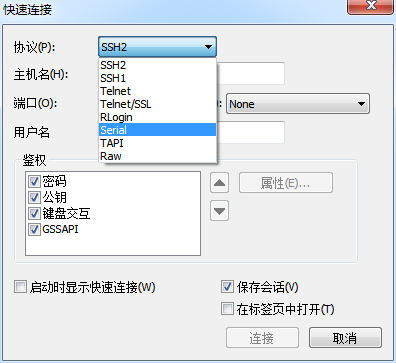
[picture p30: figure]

选择红圈中的“Serial”，出现下图

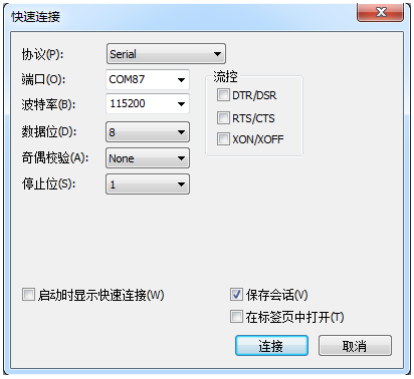
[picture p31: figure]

其中，“端口”请根据电脑中实际的串口号设置。其他设置请和上图一致。 注意:上图中的 RTS/CTS 选项一定要去掉,不然会导致终端无法输入 最后点击“连接”。出现下图

3) 如果开发板尚未上电，请将开发板配套的 DC 5V 电源连接到开发板，将其启动。启动信 息如下图所示（部分截图）

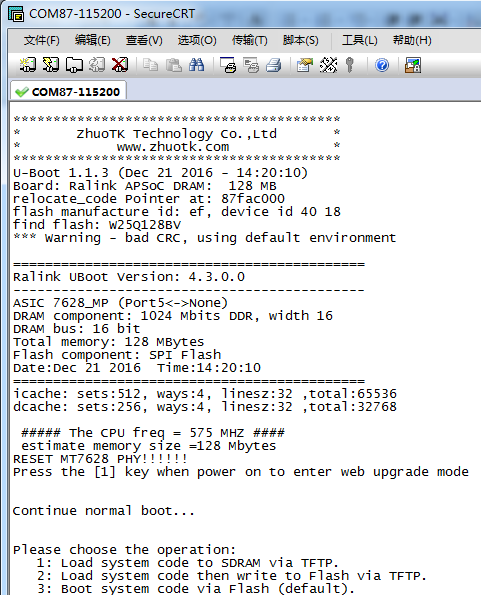
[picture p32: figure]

4) 如果此时开发板已启动完成，则按下键盘“回车键”，会出现下图

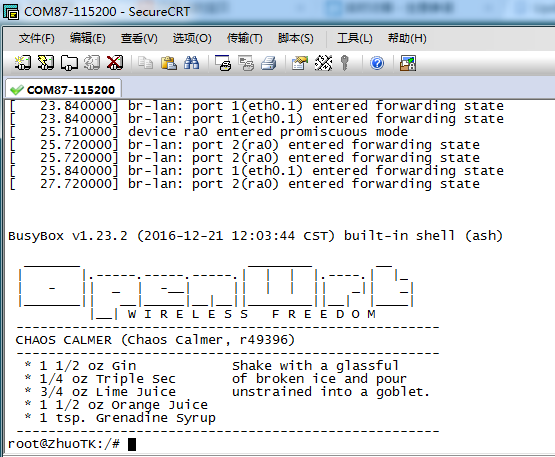
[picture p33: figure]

5) 在终端下输入“ls /”命令，出现下图

这里我们利用一个 linux 中非常常用的命令“ls”列出了系统根目录下的文件列表，至 此调试串口测试完成。

## 2.3 用 ssh 登录开发板命令行终端

我们不仅可以用调试串口登录开发板的命令行终端，因为openwrt默认带了SSH服务器，

所以还可以通过 ssh 网络登录开发板命令行终端，步骤如下 首先确保开发板和电脑网络已连接，然后同样打开 SecureCRT, 新建一个 ssh 终端

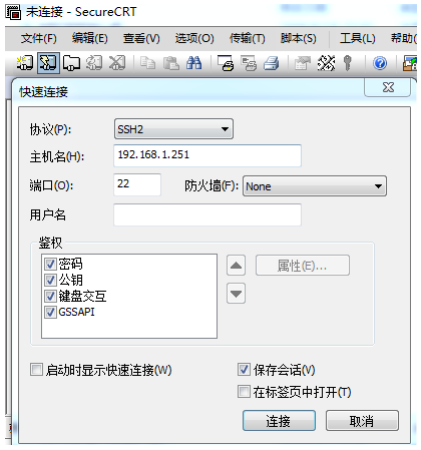
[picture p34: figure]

如上图所示，我们新建一个协议为“SSH2”的终端，连接到我们的开发板地址“192.168.1.251”。 在随后提示需要输入的用户名和密码都是“root”。成功登录后的结果，如下图所示

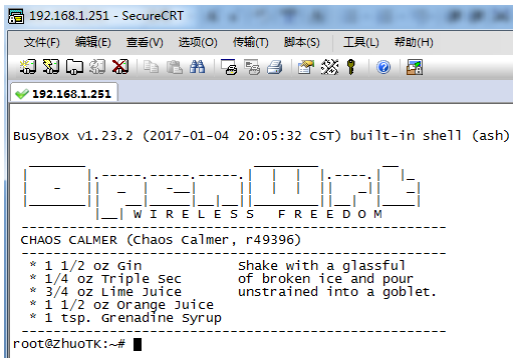
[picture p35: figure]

这个 ssh 终端的用法和“调试串口终端”用法几乎完全一致，有一点区别就是该 ssh 终端不 会打印内核调试信息。比如用户在开发板上插入 U 盘时，没有内核信息提示，不过用户可以 输入“dmesg”命令查看内核调试信息。

## 2.4 其他硬件功能测试

本文档只介绍开发板最基本的串口、wifi 功能，其他硬件测试比如 USB、TTL/RS232 串 口、TTL/485 串口、声卡等将在“JS76x8 开发板配套资料\JS76x8 开发板使用手册教程 \JS76x8 开发板 openwrt 入门教程.pdf”里面结合一些实际的应用例子做介绍。

## 3. 开发板固件镜像烧录说明

### 这里介绍 3 种在 JS76x8 开发板上烧写 openwrt 固件、uboot 镜像、eeprom 数据（联发

科无线芯片的配置数据）的方法

### 1) 用 openwrt 升级页面烧写 2) 用 uboot 升级页面烧写 3) 用 uboot+串口+网络烧写

下面我们就以在 windows 平台下为例，读者可以根据实际情况选择。注意，开发板出 厂时已烧录了完整的 openwrt 固件、uboot 镜像、eeprom 数据，一般情况无需再次烧 写。

## 3.1 用 openwrt 升级页面烧写

这种方法适用于 openwrt 系统可以正常启动的情况，可以用于 openwrt 固件的升级，如 果 openwrt 系统无法正常启动，请采用 2)或者 3)的方法。
1） 开发板上电，至启动完成。
2） 登录开发板地址“192.168.1.251”（可以用网口连接登录，也可以用 wifi 连接登录） 3） 点击系统配置页面的顶部菜单“系统”->“备份/升级”

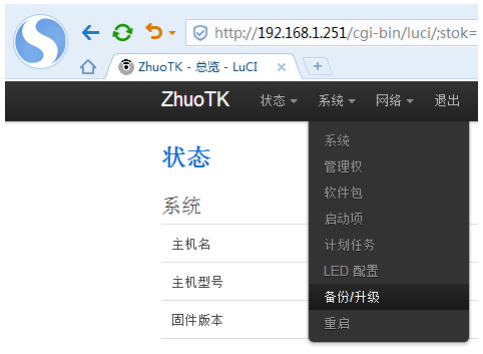
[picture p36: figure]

4） 选择页面下的“固件文件”一栏“选择文件”按钮，如下图红圈所示。

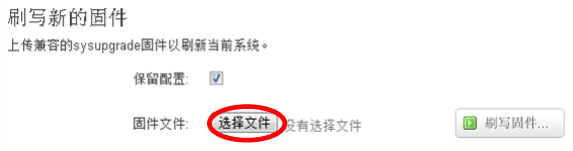
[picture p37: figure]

提示：去掉“保留配置”勾选，则系统刷新固件后，则不保留之前所做的更改。 如果勾选，则保留。
5） 在随后跳出的文件选择页面中，选中要上传的固件，并点击“打开”
6） 点击“刷写固件”
7） 如果固件正确，则会出现下图提示

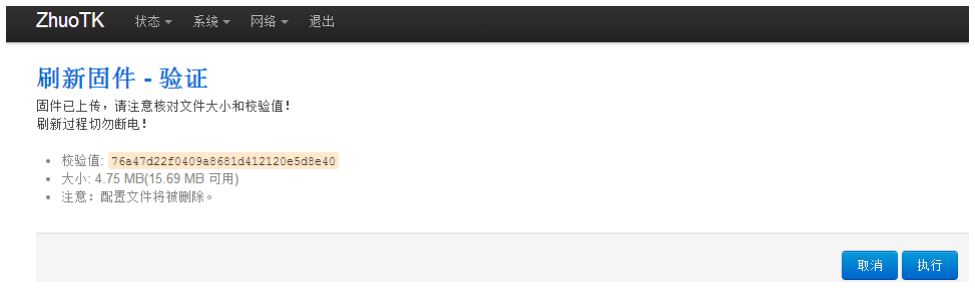
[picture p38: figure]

点击上图右下角“执行”，开始烧写固件，等待几分钟后系统刷写完成，系统自动 重启。

## 3.2 用 uboot 升级页面烧写

这里介绍的烧写方式就是网上经常说的“不死 uboot”网页烧写方式，可以用于升级 “openwrt 固件”、“uboot 镜像”、“eeprom 数据”。烧写方式如下
1) 将 PC 用网线相连接开发板任意网口。
2) 在开发板上电前，按下“RESET_FN_KEY”不放。
3) 开发板上电，“WLAN”灯亮起，接着快闪几次，说明已经进入 Uboot 网页升级页面状 态，随后可以放开“RESET_FN_KEY”按键。
4) 我们通过开发板网口登录 uboot 网页升级页面“192.168.1.8”（注意：因为板子进入 Uboot 状态后，没有 DHCP 服务器功能，如果读者的电脑是动态获取 IP 的方式，则有可能需

### 要手动设置电脑 IP 为 192.168.1.*网段，比如 192.168.1.123。否则如果电脑与开发板的

网段不同，可能会导致无法登录这个 IP 地址。），如下图所示

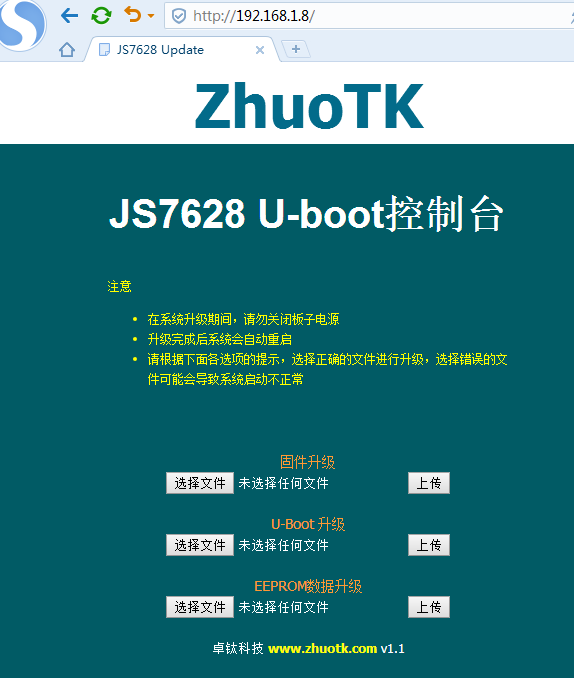
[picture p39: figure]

在此页面中我们可以升级“openwrt 固件”、“uboot 镜像”、“EEROM 数据”。这里以烧录 openwrt 固件为例，做一个介绍，步骤如下
1) 点击“选择文件”选择正确的 openwrt 固件（在“JS76x8 开发板配套资料\JS76x8 开发板固件镜像安装包\openwrt 固件\”目录下有开发板用的固件，作者用的开发

### 板是 16MB flash/128MB RAM 配置的板子，所以选择 “openwrt-ramips-mt7628-mt7628-squashfs-sysupgrade-16MB-128MB.bin”这个文件，

如下图

读者需要根据实际购买板子的配置，烧录相应的固件）
2) 点击右边对应的“上传”按钮，上传相应的文件，上传成功后，会出现下图

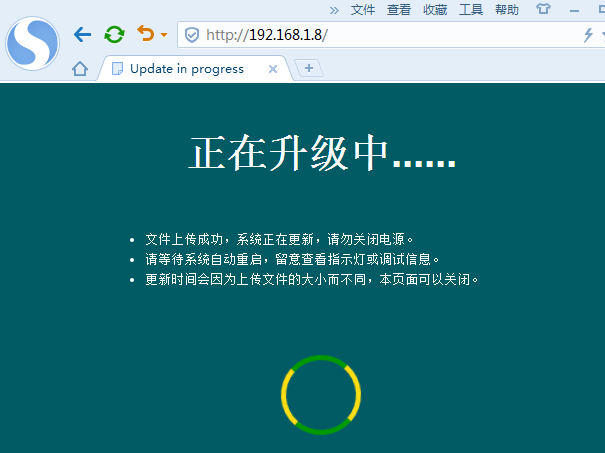
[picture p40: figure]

接着系统会自动烧写文件，然后重启，至此烧录完成，“uboot 镜像”、“EEROM 数 据”烧录步骤大同小异，这里留给读者自行实验。读者如果之前安装好调试串口， 就可以看到一系列相关系统的调试信息。
提示：在系统上电后，uboot 启动倒数计时结束前，在调试终端输入“6”，一样能使系 统进入 uboot 升级页面状态。

## 3.3 用 uboot+串口+网络烧写

这种方式是 uboot 比较通用的烧写方式，同样可以用于升级“openwrt 固件”、“uboot 镜像”、“eeprom 数据”，不过比“用 uboot 升级页面烧写”的方式繁琐一些。下面以升

级“openwrt 固件”为例做介绍，具体操作步骤如下
1) 正确设置 tftp server，启动 tftp server 服务。（读者如果不清楚如何设置，可以参考 之前的“安装 tftp server”一节）
2) 将 PC 用 mini USB 调试数据线、网线和开发板相连接。

### 3) 用 SecurCRT 打开调试终端

4) 开发板上电，在 uboot 启动倒数计时结束前，在调试终端输入“2”，出现如下图所 示

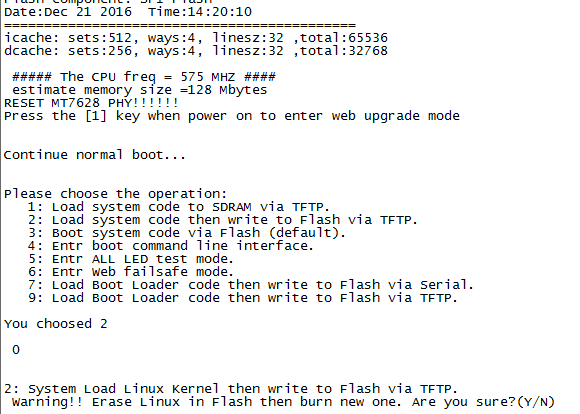
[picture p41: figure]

5) 按照提示输入“y”，并输入

### “device IP”:开发板的 IP “server IP”:电脑的 IP，读者根据自己的 IP 进行设置，“device IP”和“server IP”

必须在同一个网段，否则无法通讯

### “Input Linux Kernel filename”：openwrt 固件名称

6) 以上填写完毕后，按下“enter”键，系统会自动上传、烧写，烧写完成后会自动 重启，如下图所示

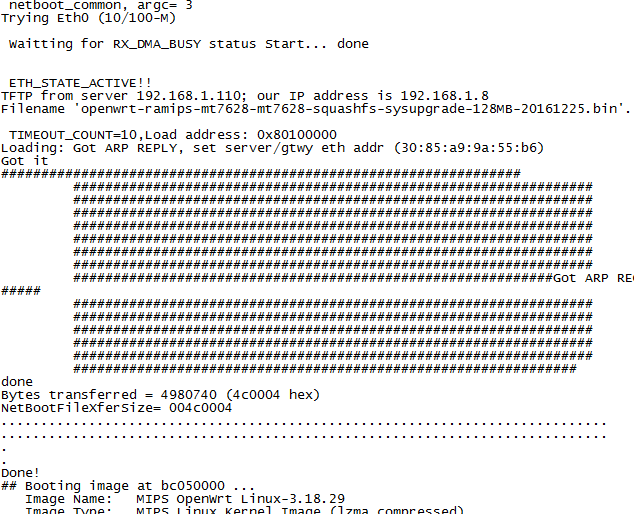
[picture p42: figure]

“uboot 镜像”的烧写方法和上面介绍的“openwrt 固件”升级方法几乎一样，只 是在 uboot 启动倒数计时结束前，在调试终端输入“9”，然后根据提示输入 uboot 镜像名称，这里不做详细介绍，读者可以自行实验。

## 3.4 用 SPI flash 烧录器烧写

用户可以用杜邦线连接开发板的“SPI 接口，flash 烧录接口，I2C 接口
” 配合本店的 SPI flash 烧录器（客户可以到 www.jotale.com (http://www.zhuotk.com/) 购买），实现对开发板 上 flash 的擦除读写等操作。烧录步骤如下
1) 在开发板和 SPI flash 烧录器都断电的情况下，连接开发板管脚和 SPI flash 烧录 器管脚，连接对应关系为
开发板 | | SPI flash 烧录器
“SPI_MISO” | <===> | “MISO”
“SPI_CS0” | <===> | “CS”
“SPI_CLK” | <===> | “CLK”
“SPI_MOSI” | <===> | “MOSI”
“GND” | <===> | “GND”
“VDD3V3_PROG” <===> | “3.3V”

提示：请读者打开开发板资料带的开发板底板原理图，查询开发板相应的管脚。
2) 电脑插上烧录器，安装好烧录器驱动，打开烧录器软件（购买烧录器后提供资料）， 选择“w25p20”型号。
3) 点击烧录软件上的“打开”按钮，在“JS76x8 开发板配套资料\开发板固件镜像安 装包\uboot 镜像\”中选择对应的 uboot 镜像。
4) 点击“擦除”按钮，烧录器对开发板进行擦除操作，接着擦除完成。
5) 点击“编程”按钮，烧录器对开发板进行写入操作，接着写入完成。（注意：这一 步读者可能需要拔掉烧录器重新插上才能成功进行“编程”操作）
6) 点击“校验”按钮，看一下否是提示“校验成功”。成功的话则继续下一步操作，

不成功则需要重新从第 4 步开始。
7) 拔掉烧录器杜邦线，使烧录器与开发板的连接断开，给开发板上电，并查看调试串 口有无调试信息输出，如果有则代表 uboot 已经启动了。
8) 通过网页重新烧录“固件”、“EEPROM 数据”
9) 系统正常启动

## 4. 修改默认的 MAC 地址

JS76x8 板子出厂时每一块板子已经设置了不同的 MAC 地址，一般不建议客户修改 MAC 地址，如果用户确实需要修改板子的默认 MAC 地址，可以按照下面两种方式修改。 方法 1：
在开发板启动时候，在调试串口终端中，根据系统提示，按键输入“4”进入 Uboot 控制台

并执行命令

### "setmac 0 xx:xx:xx:xx:xx:xx"（设置第 0 个 MAC 地址，“xx:xx:xx:xx:xx:xx”为 MAC 地址） "setmac 1 xx:xx:xx:xx:xx:xx"（设置第 1 个 MAC 地址，“xx:xx:xx:xx:xx:xx”为 MAC 地址） "setmac 2 xx:xx:xx:xx:xx:xx"（设置第 2 个 MAC 地址，“xx:xx:xx:xx:xx:xx”为 MAC 地址）

如下图所示。

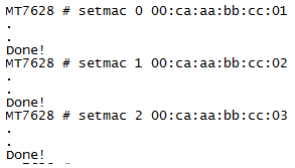
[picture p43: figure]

执行“printmac”可以看到修改后的 MAC 地址，如下图所示

执行“reset”命令，重启开发板，等板子启动完全后，可以看到修改后的 MAC 地址已 经更新到 openwrt 系统了，如下图所示

提示：有时候，openwrt 系统可能会记录下之前设置的 MAC 地址，此时用户如果想用新的 MAC 地址，可 以尝试将板子恢复出厂设置，通过这种方法修改 MAC 地址，重刷 openwrt 或者 openwrt 恢复出厂设置 MAC

地址不会丢失。

方法 2：
修改openwrt的“/etc/config/network”文件。修改需要更改MAC地址接口的“macaddr” 字段，指定新的 MAC 地址。比如将“lan”接口的“macaddr”字段修改为下图

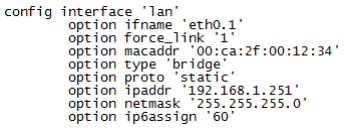
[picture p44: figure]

执行“/etc/init.d/network restart”重启开发板网络接口或重启开发板，接着执行 “ifconfig”查看修改结果，如下图所示

从上图我们可以看到“lan”接口的 MAC 地址已经变为新的了。 注意：不建议用此方法修改 MAC 地址，因为用这个方式设置的 MAC 地址，在开发板恢复出 厂设置后随即失效，并且在操作的时候会因为删除接口而消失。

## 5. 版本历史

版本 | 时间 | 修改说明
V1.0 | 2016.12.19 | JS7628 开发板使用手册初始版本
V1.1 | 2017.01.10 | 增加了通过 ssh 登录开发板命令终端的说明
V1.2 | 2017.11.22 | 添加了 SPI flash 烧录说明
V1.3 | 2018.02.01 | 修正了 SPI 烧录器连接管脚说明
V1.4 | 2019.06.24 | 修改了 secureCRT 的安装说明
V1.5 | 2019.12.01 | 修正了有关“ls”显示目录的说明
V1.6 | 2020.05.12 | 将“JS7628 开发板手册”修改为“JS76x8 开发板使用手册” 修改了“修改默认的 MAC 地址”的说明

V1.7 | 2020.11.23 | 将“JS7628”的说明改为“JS76x8”。 修改了有关按键进入 Uboot 的说明、LED 网口灯的说明。
V1.8 | 2020.12.12 | 修改了有关烧录固件和按键的说明。 修改了 Uboot 升级的说明。
V1.9 | 2021.01.16 | 修改了“用 SPI flash 烧录器烧写”一节中 Uboot 文件路径的说明。

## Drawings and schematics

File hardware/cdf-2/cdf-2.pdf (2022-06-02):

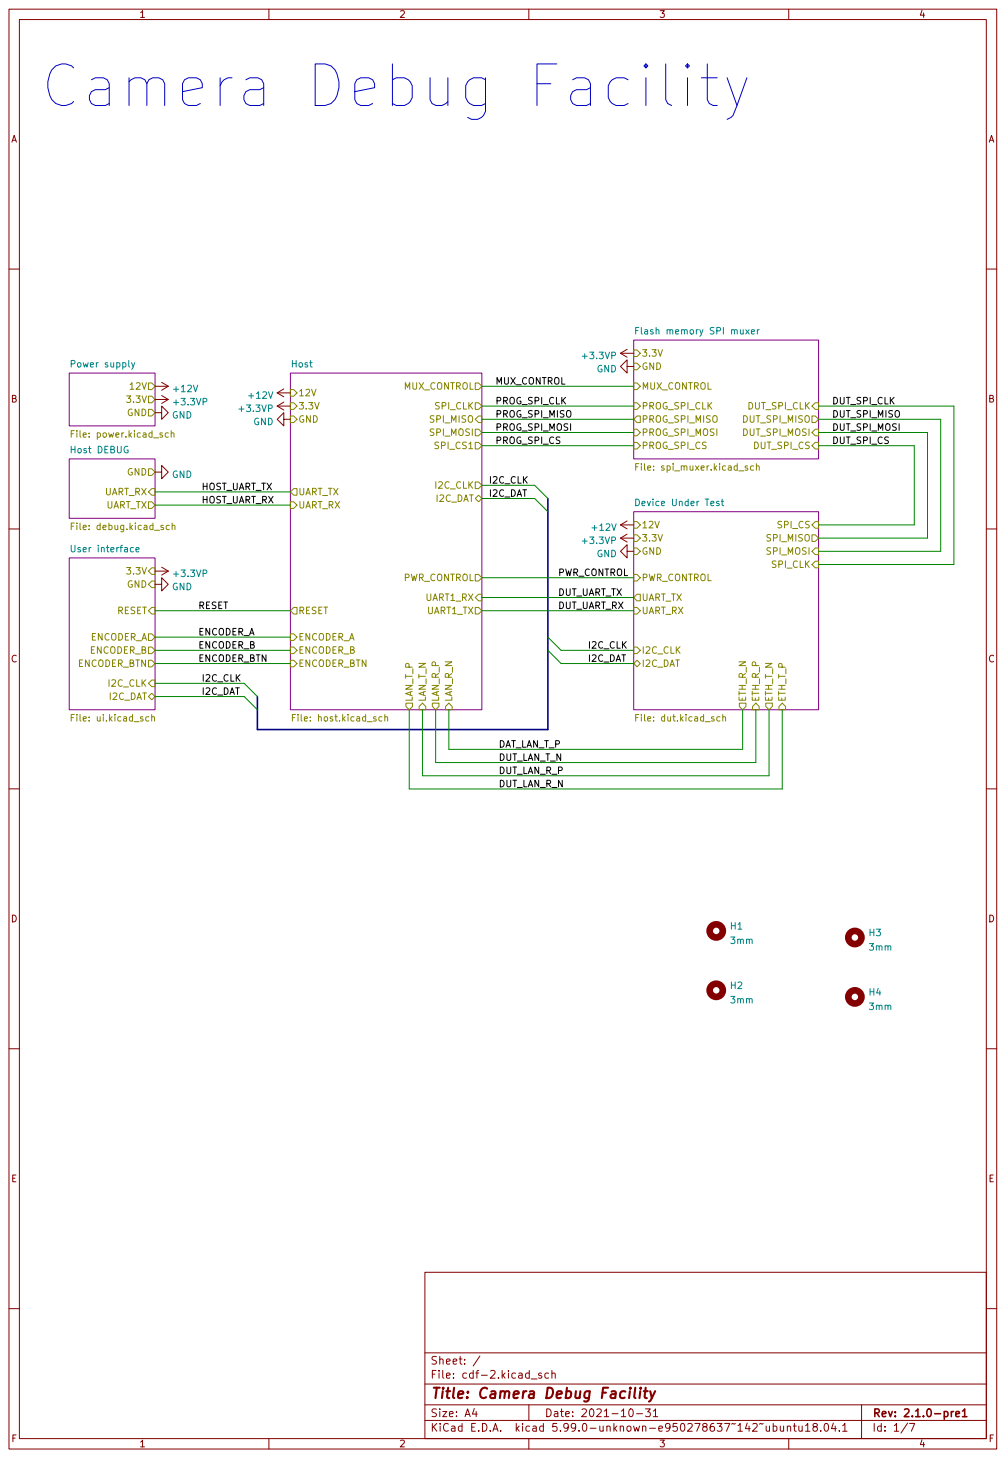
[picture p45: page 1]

Flash memory SPI muxer

DUT_UART_RX

ENCODER_A | | I2C_CLK

File: cdf-2.kicad_sch Sheet: /
Id: 1/7 Title: Camera Debug Facility

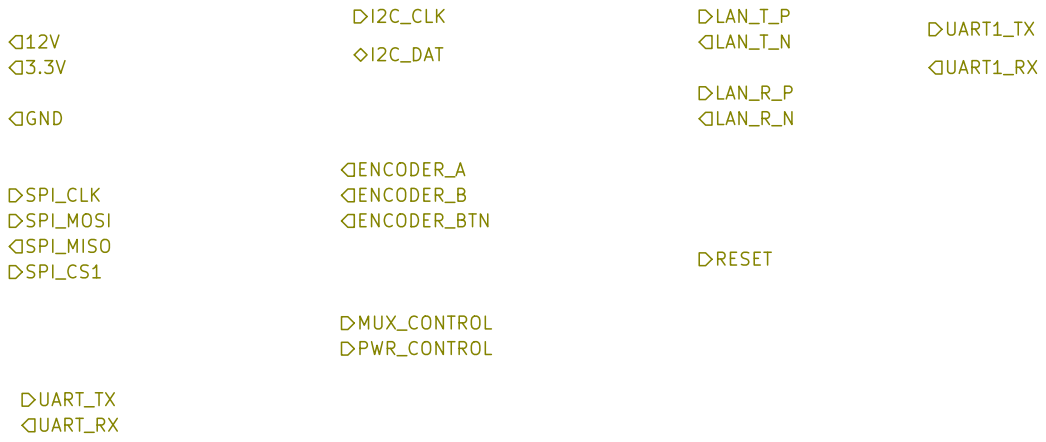
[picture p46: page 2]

File: host.kicad_sch Sheet: /Host/
Id: 2/7 Title: Camera Debug Facility

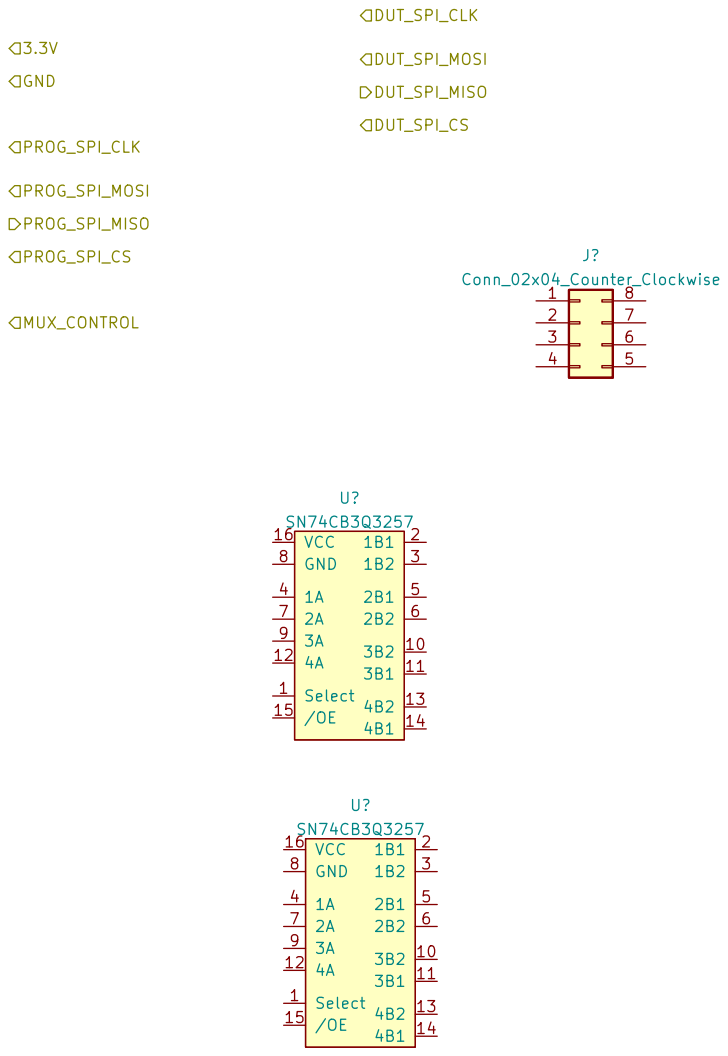
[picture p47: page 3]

Sheet: /Flash memory SPI muxer/
File: spi_muxer.kicad_sch
Id: 3/7 Title: Camera Debug Facility

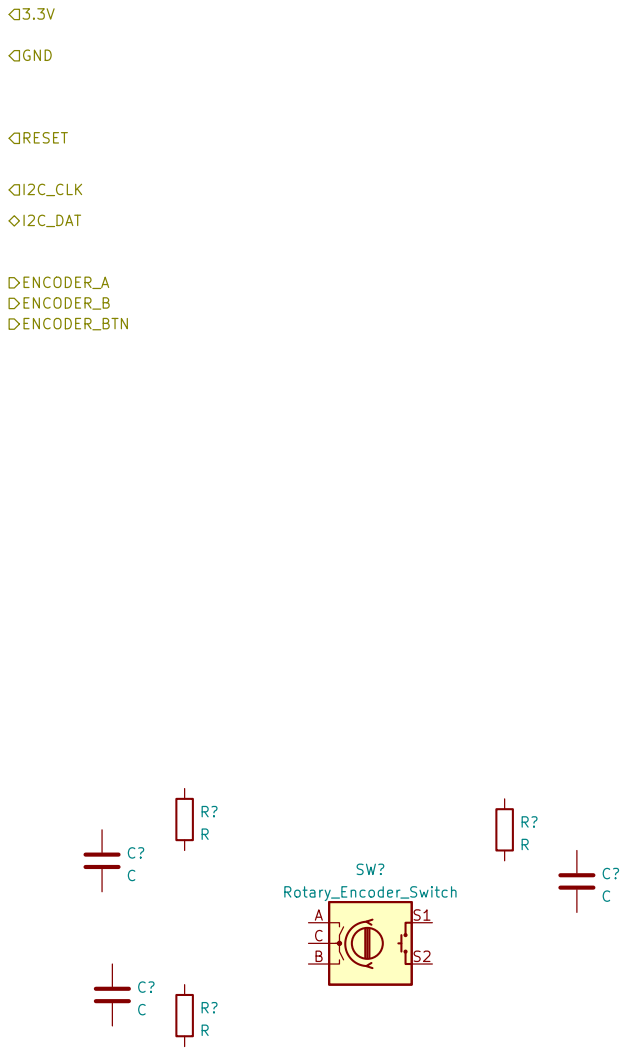
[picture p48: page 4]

File: ui.kicad_sch Sheet: /User interface/
Id: 4/7 Title: Camera Debug Facility

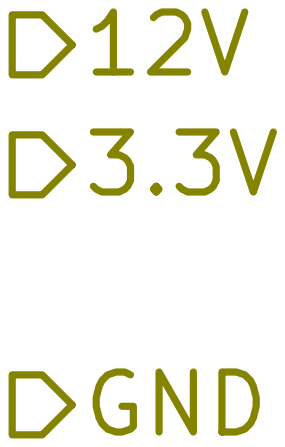
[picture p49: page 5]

Sheet: /Power supply/
File: power.kicad_sch
Id: 5/7 Title: Camera Debug Facility

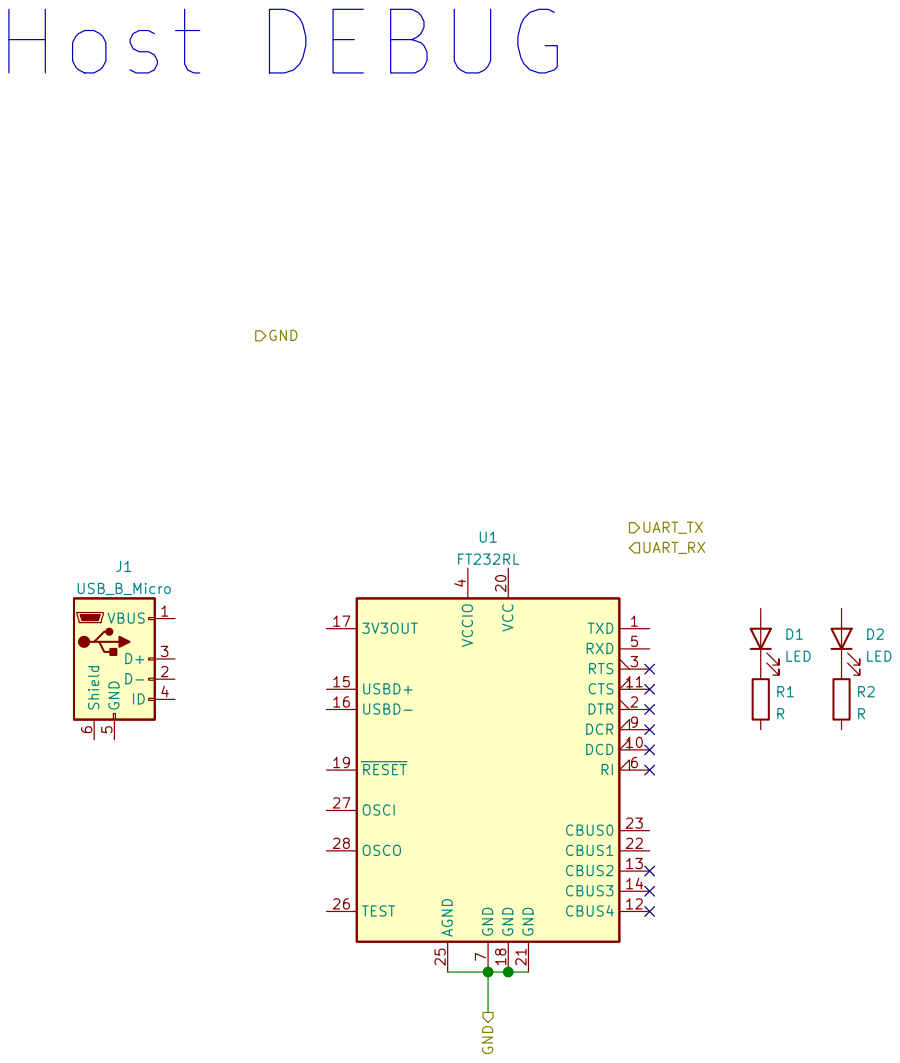
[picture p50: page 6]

File: debug.kicad_sch Sheet: /Host DEBUG/
Id: 6/7 Title: Camera Debug Facility

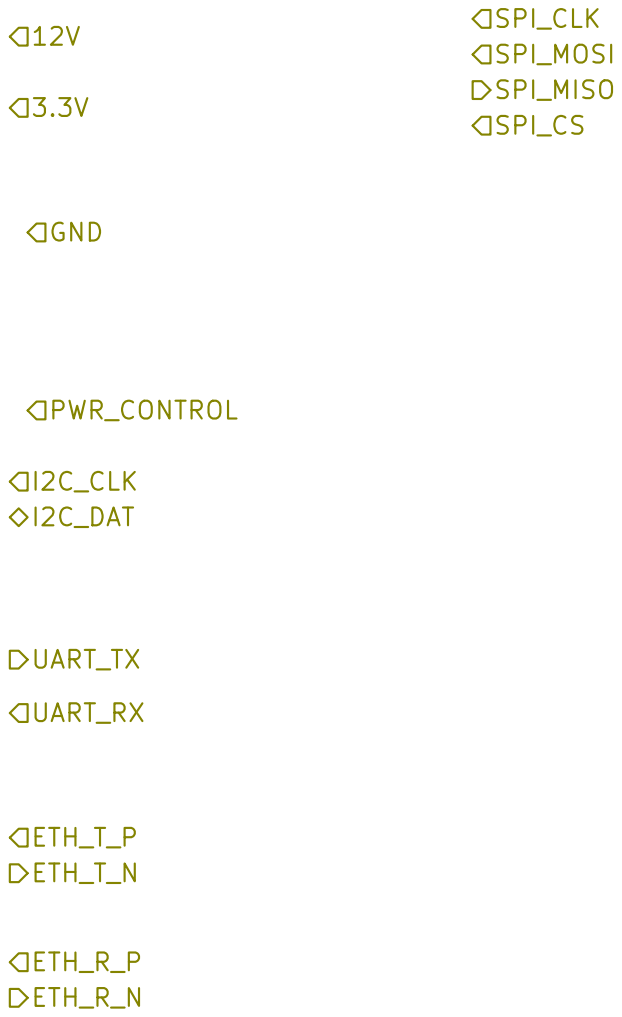
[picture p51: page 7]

File: dut.kicad_sch Sheet: /Device Under Test/
Id: 7/7 Title: Camera Debug Facility

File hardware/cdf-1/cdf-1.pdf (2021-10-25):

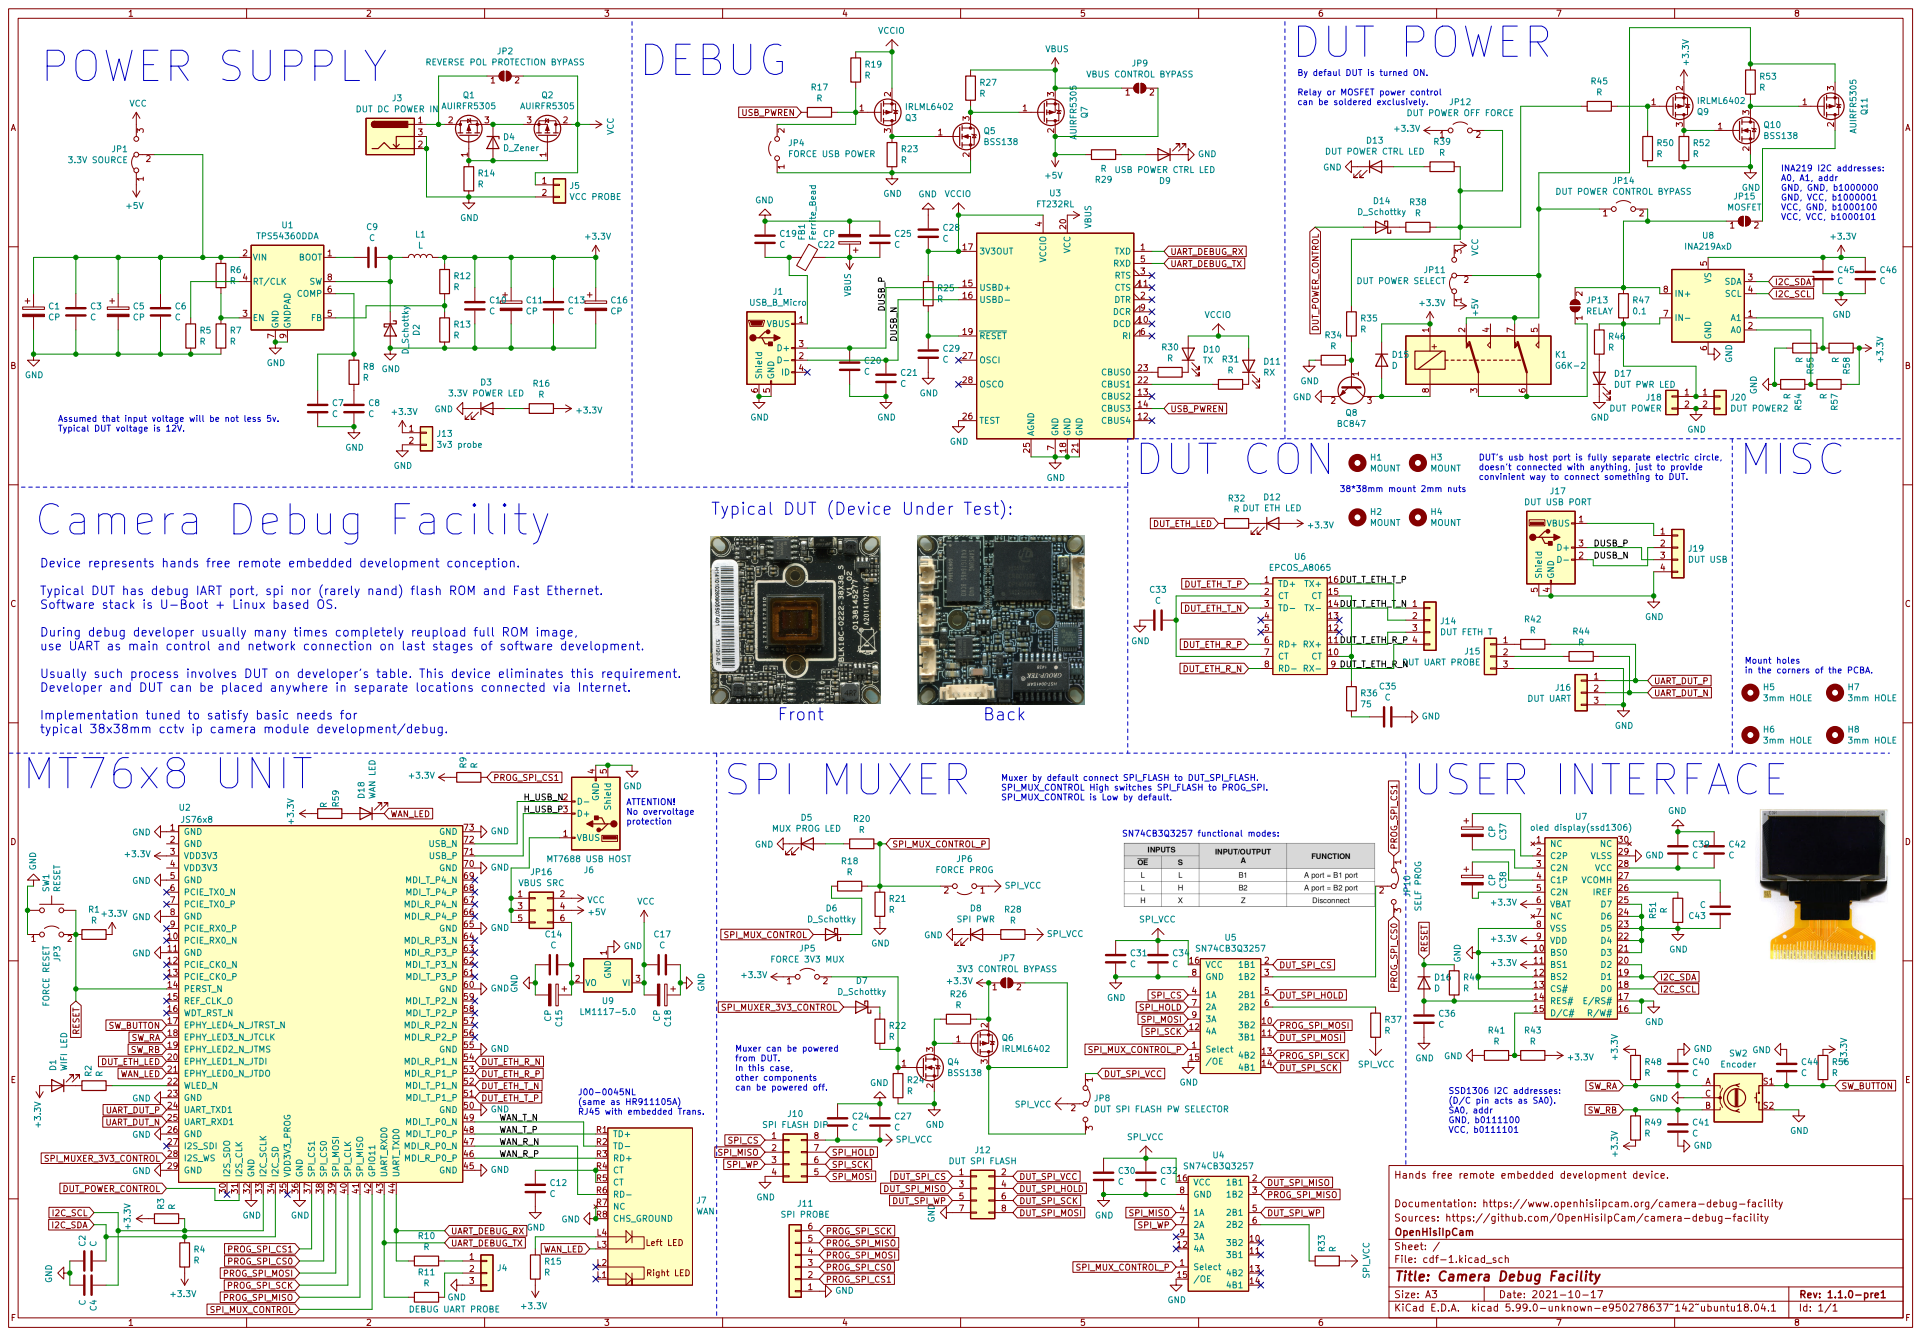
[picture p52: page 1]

(same as HR911105A) RJ45 with embedded Trans. DEBUG

JP2 REVERSE POL PROTECTION BYPASS

JP9 VBUS CONTROL BYPASS D9 USB POWER CTRL LED

By defaul DUT is turned ON.

Relay or MOSFET power control
can be soldered exclusively.

J3 DUT DC POWER IN

JP12 DUT POWER OFF FORCE

D14 D_Schottky D13 DUT POWER CTRL LED GND

INA219 I2C addresses: A0, A1, addr GND, GND, b1000000 GND, VCC, b1000001 VCC, GND, b1000100 VCC, VCC, b1000101 SPI MUXER

JP14 DUT POWER CONTROL BYPASS

TXD 1 DCD 10 CTS 11 CBUS4 12 CBUS2 13 CBUS3 14 USBD+ 15 USBD- 16

D17 DUT PWR LED GND

Assumed that input voltage will be not less 5v.
Typical DUT voltage is 12V.
Camera Debug Facility

in the corners of the PCBA. DUT CON

DUT's usb host port is fully separate electric circle,
doesn't connected with anything, just to provide

Device represents hands free remote embedded development conception.

Typical DUT has debug IART port, spi nor (rarely nand) flash ROM and Fast Ethernet.
Software stack is U-Boot + Linux based OS.

During debug developer usually many times completely reupload full ROM image,
use UART as main control and network connection on last stages of software development.

Usually such process involves DUT on developer's table. This device eliminates this requirement.
Developer and DUT can be placed anywhere in separate locations connected via Internet.
MT76x8 UNIT

Implementation tuned to satisfy basic needs for
typical 38x38mm cctv ip camera module development/debug.

SN74CB3Q3257 functional modes: Muxer by default connect SPI_FLASH to DUT_SPI_FLASH.
SPI_MUX_CONTROL High switches SPI_FLASH to PROG_SPI.

SPI_MUX_CONTROL is Low by default. ATTENTION! No overvoltage

LM1117-5.0GND C15 CP GND GND GND

Hands free remote embedded development device. GND

SSD1306 I2C addresses: (D/C pin acts as SA0). SA0, addr GND, b0111100 VCC, b0111101 Muxer can be powered
from DUT.
In this case, other components

can be powered off.

3 JP8 DUT SPI FLASH PW SELECTOR GND GND

J10 SPI FLASH DIP GND GND

Documentation: https://www.openhisiipcam.org/camera-debug-facility
Sources: https://github.com/OpenHisiIpCam/camera-debug-facility
File: cdf-1.kicad_sch Sheet: / OpenHisiIpCam

Id: 1/1 Title: Camera Debug Facility

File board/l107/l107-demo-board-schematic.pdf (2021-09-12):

# POWER

1 SW | 4 SW | 2 COM | 5 COM | 3 SW | 6 SW

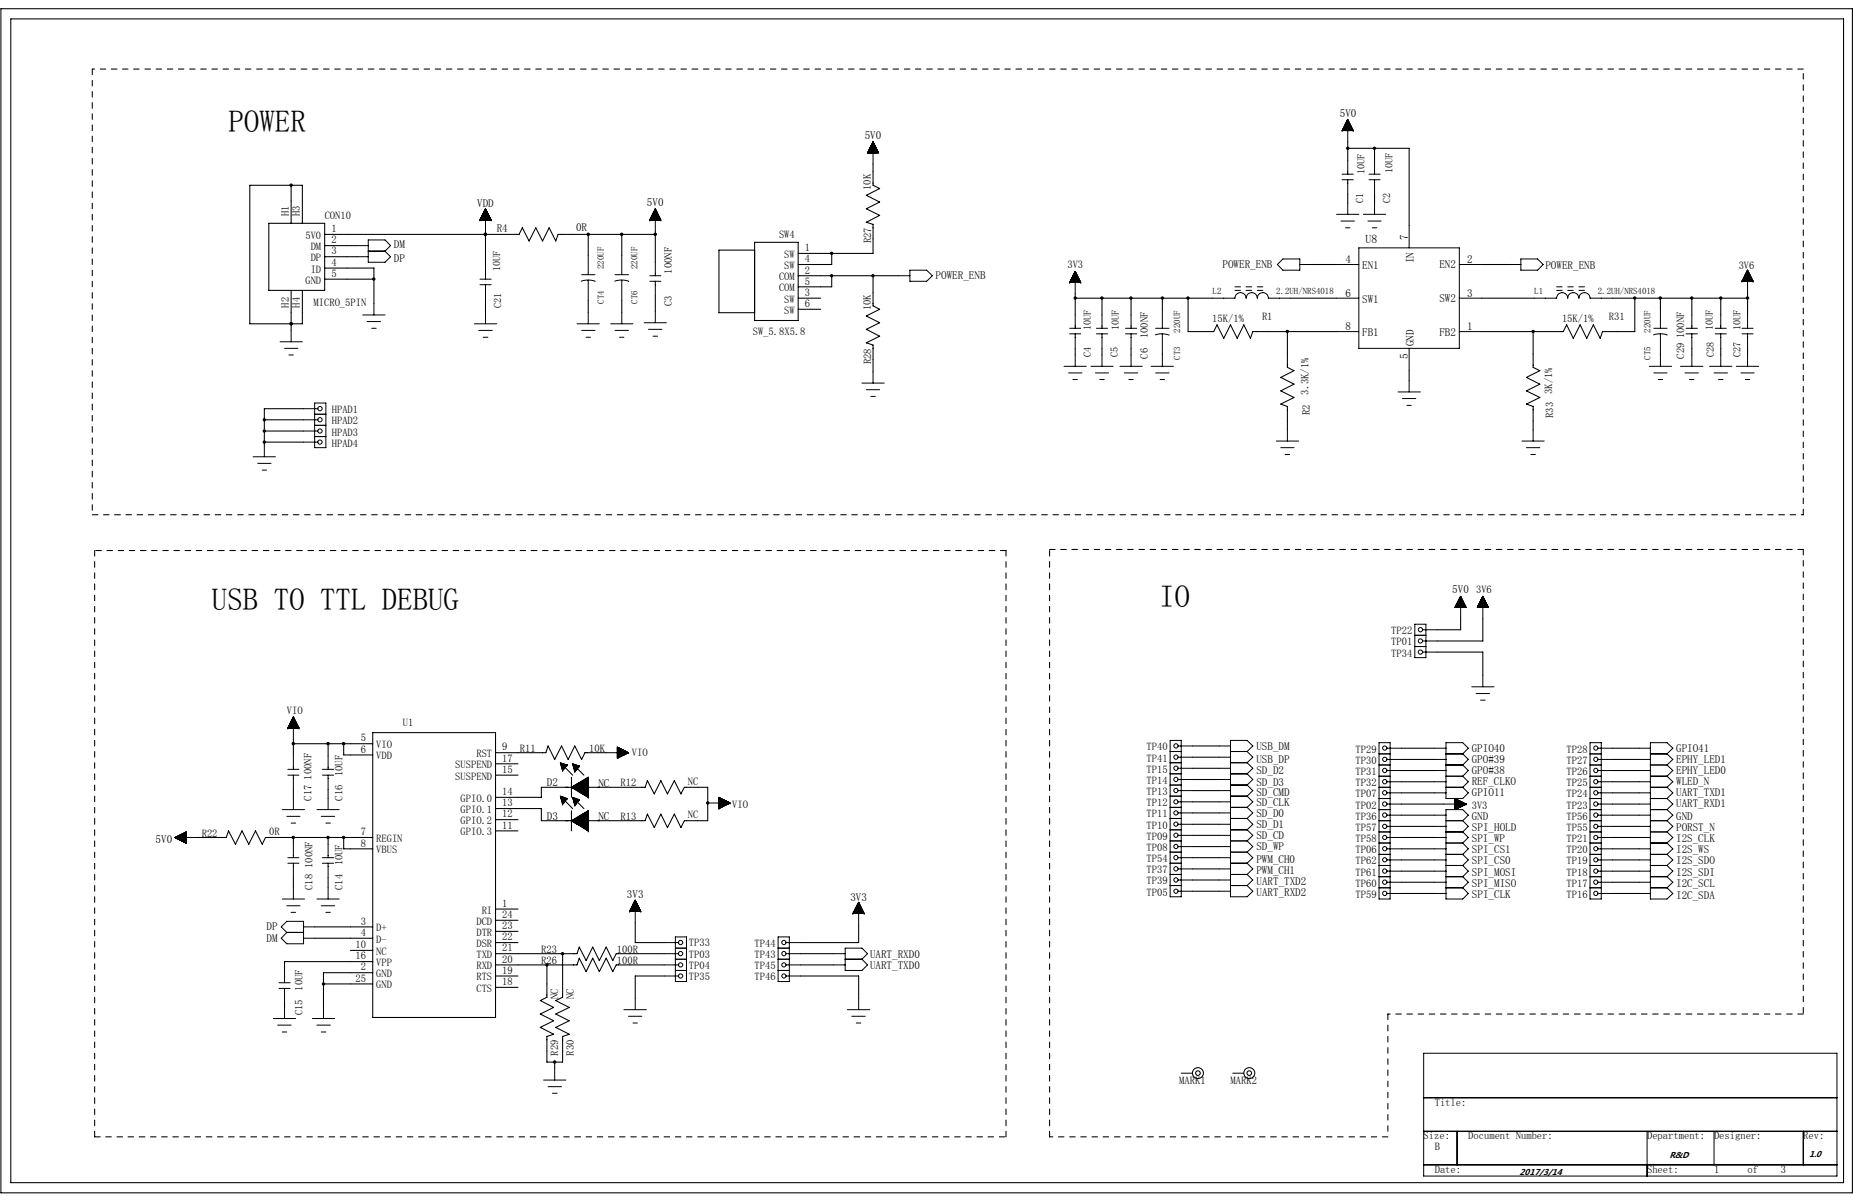
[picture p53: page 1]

Size: B | Document Number: | Department: R&D | Designer: | Rev: 1.0

Date: 2017/3/14 | | Sheet: 1 of 3

# WIFI MODULE

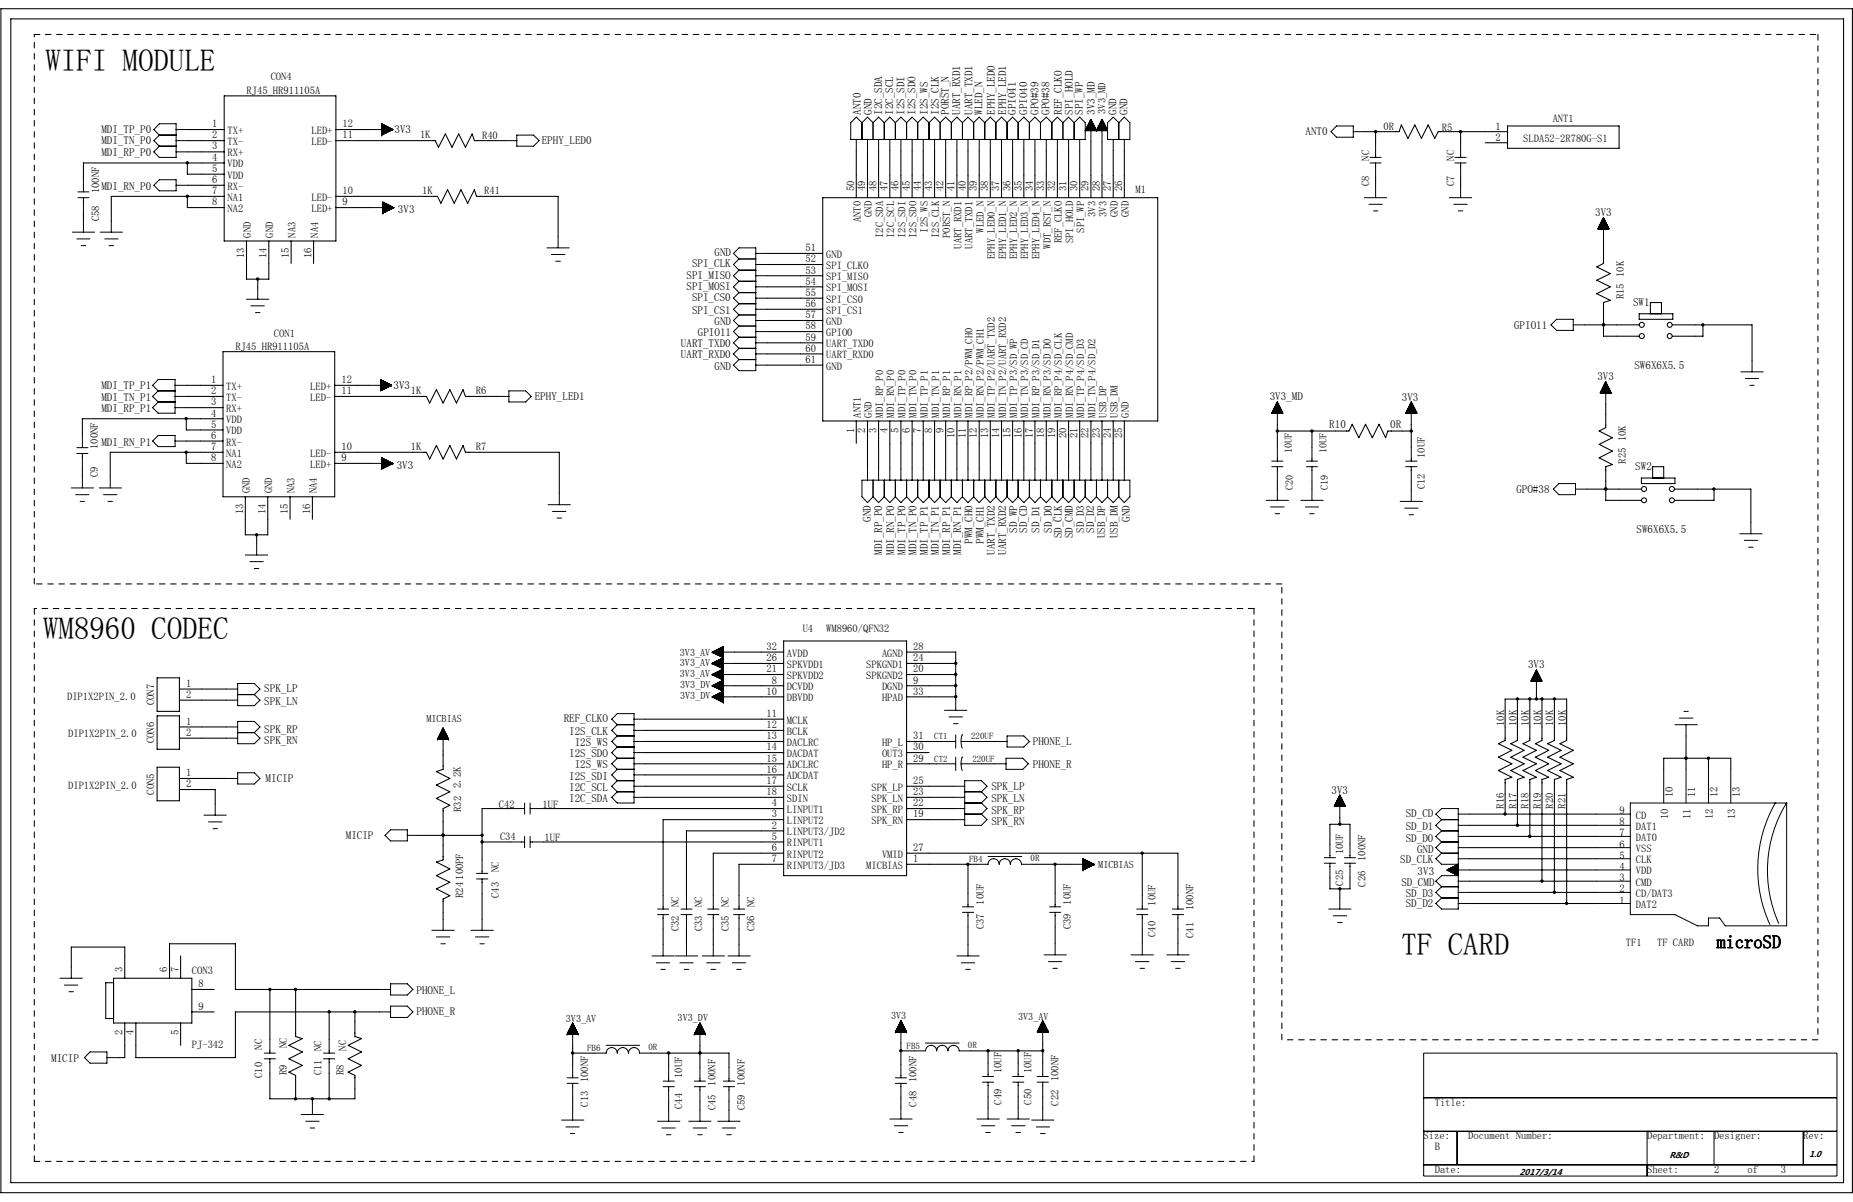
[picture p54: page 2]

Size: B | Document Number: | Department: R&D | Designer: | Rev: 1.0

Date: 2017/3/14 | | Sheet: 2 of 3

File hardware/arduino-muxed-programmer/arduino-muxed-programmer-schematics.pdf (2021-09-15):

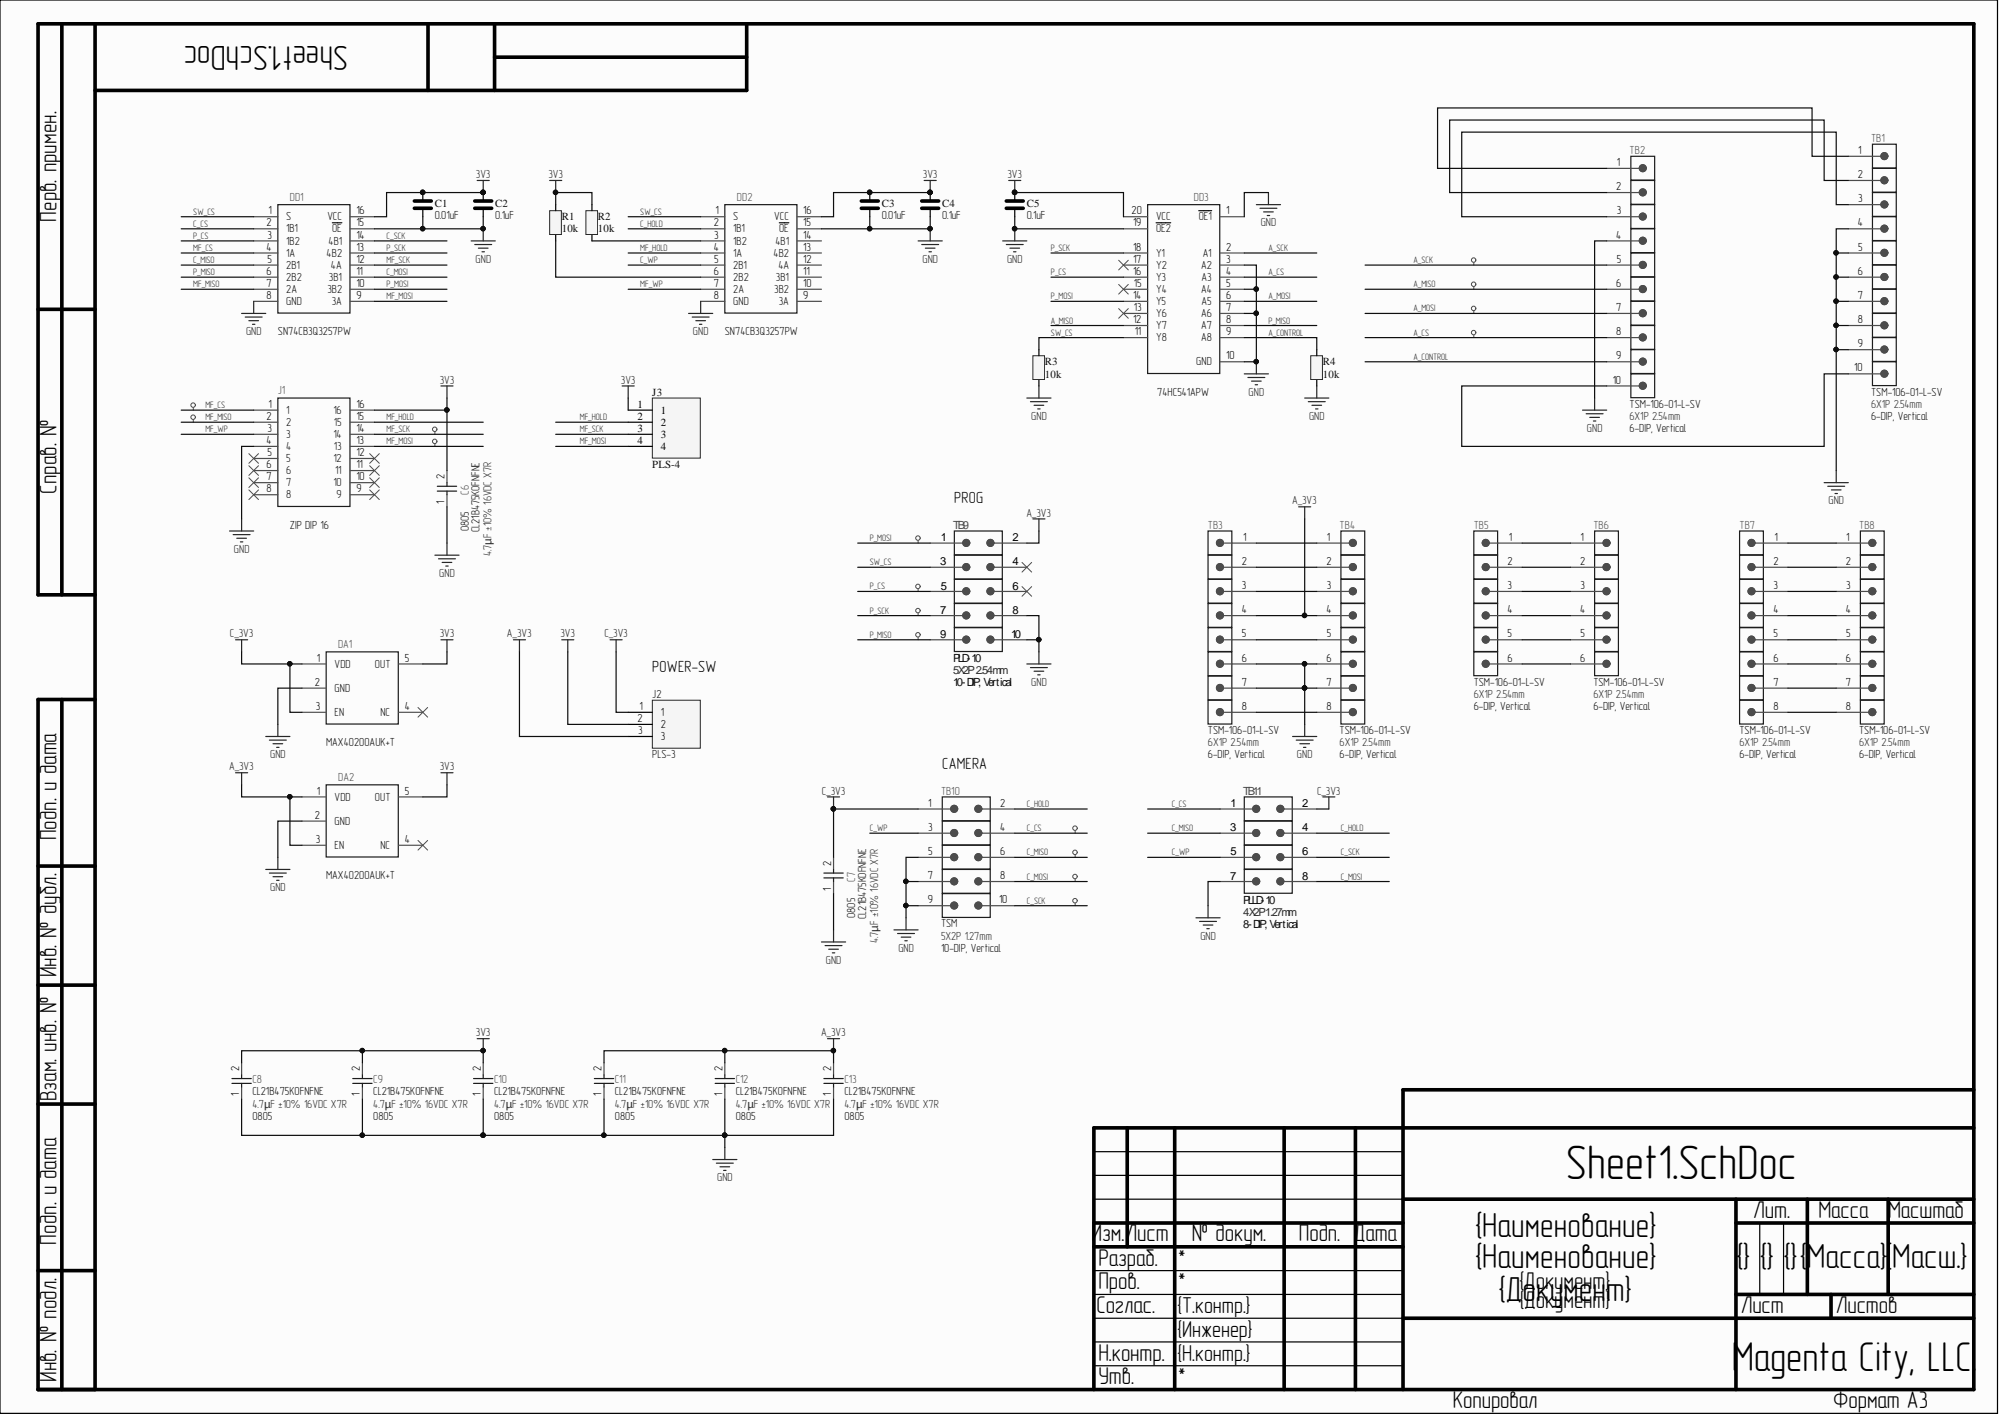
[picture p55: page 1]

Инв. № подл. Инв. № дубл. Подп. и да

Sheet1.SchDoc

{Наименование} {Наименование} {Документ} {Документ} {Документ} | Лит. | Масса | Масштаб

Лист | № докум. * | | {} {} {} | | {Масса} | {Масш.}

Пров. | *
Соглас. | {Т.контр.} | Лист | Листов

{Инженер}

Утв. Н.контр. | {Н.контр.}

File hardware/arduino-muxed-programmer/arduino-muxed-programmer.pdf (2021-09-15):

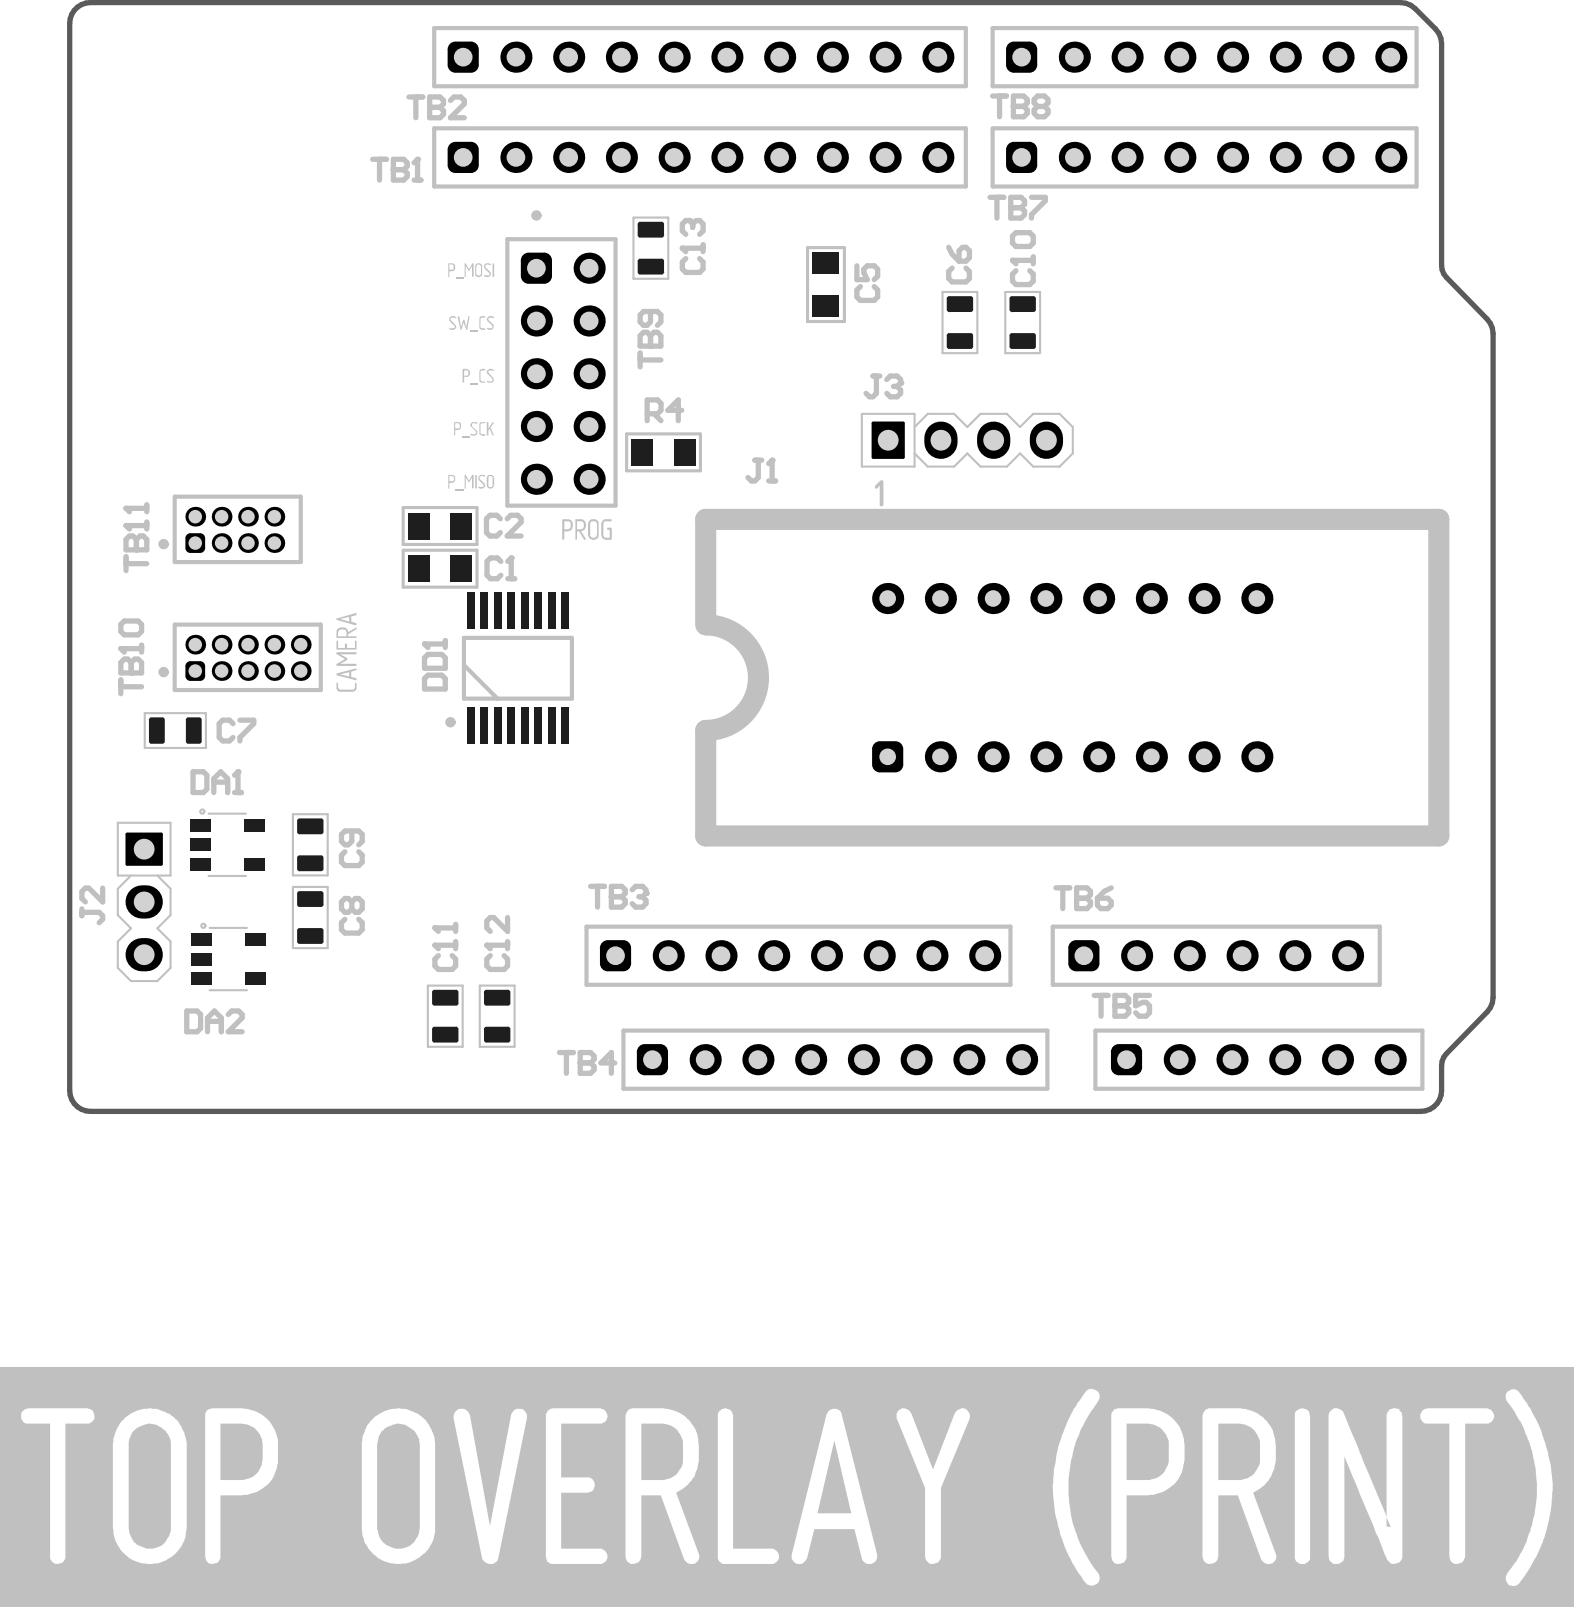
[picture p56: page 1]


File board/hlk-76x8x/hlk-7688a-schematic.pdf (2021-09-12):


TXON1 3 RXIP1 4 | NC 4

8 RXIP2 9 TXON2 10 | | NC 5

RXIP1 3


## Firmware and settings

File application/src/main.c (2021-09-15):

/*
 * Copyright (c) 2021 OpenHisiIpCam, info@openhisiipcam.org
 * SPDX-License-Identifier: MIT
 */

#include <assert.h>
#include <getopt.h>
#include <stdio.h>
#include <string.h>

#include <libwebsockets.h>
#include <uv.h>

//#include "lws/lws.h"

typedef struct
{
  uv_loop_t loop_uv;         ///< libuv instance
  uv_signal_t sighandler_uv; ///< signal handler (via libuv)
  //lws_t* lws;                ///< libwebsockets ws/http server instance
} application_t;


static void
signal_cb_uv(uv_signal_t* watcher, int signum)
{
  //streamer_t* streamer = watcher->data;

  //lwsl_notice("Signal %d caught...\n", signum);

  switch (signum) {
    case SIGTERM:
    case SIGINT:
      break;
    default:
      break;
  }

  //uv_stop(&streamer->loop_uv);
}


int
main()
{
  printf("application\n");

  application_t application;
 int r;

  r = uv_loop_init(&application.loop_uv); /// @todo check return
  if (0 != r) {
    printf("UV loop init failed!\n");
    /// @todo check return error values
    goto shutdown;
  }
  printf("UV loop inited.\n");

  /*
  uv_signal_init(&streamer.loop_uv, &streamer.sighandler_uv);

  streamer.sighandler_uv.data = &streamer;

  uv_signal_start(&streamer.sighandler_uv, signal_cb_uv, SIGINT);
  */
shutdown:
  return 0;
}

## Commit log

2021-09-12 initial sw
    [cdf-1.kicad_pcb, cdf-1.sch]
2021-09-15 arduino muxed programmer and adapters
    [A1.GBL, A1.GBO, A1.GBP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]
2021-09-18 minimal working system
    [16MB.cfg]
2021-09-18 system env initial
    [16MB.cfg]
2021-09-19 programmer speed test
    [16MB.cfg]
2021-09-21 i2c tests
2021-10-09 1st prototype
    [32MB.cfg, cdf-1.sch]
2021-10-12 schematics 1.1.0
    [cdf-1.kicad_pcb]
2021-10-25 PCB probe
    [105450-0101.step, WMS-7628N封装尺寸.DWG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]
